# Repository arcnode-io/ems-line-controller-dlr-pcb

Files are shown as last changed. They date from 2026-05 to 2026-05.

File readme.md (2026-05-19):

# DLR PCB 🌡️⚡







> Single-PCB CM4 carrier for a solar-powered, cellular-connected RTU — mounts to a transmission tower cross-arm, integrates SoM + cellular modem + IEEE 738 sensor suite + solar/LiFePO4 power management. Feeds [`dlr-operating-envelope`](https://gitlab.com/arcnode-io/dlr-operating-envelope).

Solar-powered remote terminal unit (RTU) deployed unattended on transmission tower cross-arms. A ~20W solar panel and ~50Wh LiFePO4 battery keep the CM4 running indefinitely with cellular PSM idle. A soldered Quectel BG770A (LTE Cat-M1) publishes sensor data and dynamic ratings to the MQTT broker — no site WiFi or wired backhaul required. The unit is designed for 30-year conductor-adjacent deployment with no scheduled maintenance.

~100x80mm 4-layer industrial carrier. Raspberry Pi CM4 (DF40 dual-connector) + Quectel BG770A LCC + FLIR Lepton 3.5 (SPI) + DHT22 (GPIO) + SI1145 (I2C) + YL-83 (analog via ADS1115). MPPT charger from PV input, LiFePO4 BMS, buck for 5V SoM rail, AP2112K LDO for 3.3V analog front-end. Conformal coated, IP55 when potted in field enclosure.

## System Context

```plantuml
rectangle transmission_tower {
  rectangle field_enclosure {
    rectangle dlr_carrier {
      rectangle cm4_som
      rectangle cellular_module
      rectangle sensors
      rectangle power_mgmt
    }
  }
  rectangle solar_panel
  rectangle lifepo4_battery
  rectangle conductor
}

queue mqtt_broker
rectangle dlr_pst_sim

solar_panel -d- power_mgmt: PV input
power_mgmt -l- lifepo4_battery: charge / discharge
power_mgmt -d- cm4_som: 5V / 3V3
conductor -u- sensors: thermal view\n(FLIR Lepton)
sensors -r- cm4_som: SPI / I2C / GPIO
cm4_som -r- cellular_module: UART + USB2
cellular_module -r- mqtt_broker: LTE Cat-M1
mqtt_broker -r- dlr_pst_sim: tap \n adjustment \n commands
```

The carrier is the physical sensing + edge-compute layer of the DLR feedback loop. Every measurement flows through the IEEE 738 calculation in [`dlr-operating-envelope`](https://gitlab.com/arcnode-io/dlr-operating-envelope) and ultimately determines whether the phase shift transformer adjusts its tap position.

## Board Spec

```mermaid
graph LR
    SOLAR["Solar Panel<br/>~20W 12V"] --> MPPT["MPPT Charger"]
    MPPT --> BAT["LiFePO4 4S<br/>~50Wh + BMS"]
    BAT --> BUCK["Buck<br/>5V 3A"]
    BUCK --> CM4["CM4 SoM<br/>DF40 x2"]
    BUCK --> BG["Quectel BG770A<br/>Cat-M1 LCC"]
    BUCK --> LDO["AP2112K<br/>3.3V LDO"]
    LDO --> ADC["ADS1115<br/>I2C 0x48"]
    LDO --> UV["SI1145<br/>I2C 0x60"]
    CM4 --> FLIR["FLIR Lepton 3.5<br/>SPI0 + GPIO25"]
    CM4 --> DHT["DHT22<br/>GPIO4"]
    CM4 --> ADC
    CM4 --> UV
    ADC --> RAIN["YL-83<br/>Analog 0-3.3V"]

    style SOLAR fill:#dc4,stroke:#333
    style MPPT fill:#a94,stroke:#333
    style BAT fill:#a94,stroke:#333
    style BUCK fill:#a94,stroke:#333
    style LDO fill:#a94,stroke:#333
    style CM4 fill:#4a9,stroke:#333,color:#fff
    style BG fill:#49a,stroke:#333,color:#fff
    style FLIR fill:#49a,stroke:#333,color:#fff
    style DHT fill:#94a,stroke:#333,color:#fff
    style ADC fill:#94a,stroke:#333,color:#fff
    style UV fill:#94a,stroke:#333,color:#fff
    style RAIN fill:#669,stroke:#333,color:#fff
```

## CM4 Pinout

```mermaid
flowchart LR
classDef default fill:transparent,stroke:#333
classDef pwr fill:#4a9,stroke:#333,color:#fff
classDef spi fill:#49a,stroke:#333,color:#fff
classDef i2c fill:#94a,stroke:#333,color:#fff
classDef gpio fill:#a94,stroke:#333,color:#fff
classDef uart fill:#a49,stroke:#333,color:#fff
classDef usb fill:#669,stroke:#333,color:#fff

subgraph cm4 ["CM4 (DF40-100)"]
  p_5v["5V_IN"]
  p_sda["GPIO2 SDA1"]
  p_scl["GPIO3 SCL1"]
  p_g4["GPIO4"]
  p_g25["GPIO25"]
  p_mosi["GPIO10 MOSI"]
  p_miso["GPIO9 MISO"]
  p_sck["GPIO11 SCLK"]
  p_ce0["GPIO8 CE0"]
  p_txd["GPIO14 TXD"]
  p_rxd["GPIO15 RXD"]
  p_usb["USB2 D+/D-"]
end

subgraph onboard ["Carrier Components"]
  flir["FLIR Lepton 3.5"]
  dht["DHT22"]
  si["SI1145"]
  ads["ADS1115"]
  yl["YL-83"]
  bg["BG770A"]
end

p_mosi --> flir
p_miso --> flir
p_sck --> flir
p_ce0 --> flir
p_g25 --> flir
p_g4 --> dht
p_sda --> si
p_scl --> si
p_sda --> ads
p_scl --> ads
ads --> yl
p_txd --> bg
p_rxd --> bg
p_usb --> bg

class p_5v pwr
class p_mosi,p_miso,p_sck,p_ce0 spi
class p_sda,p_scl i2c
class p_g4,p_g25 gpio
class p_txd,p_rxd uart
class p_usb usb
```

## Sensor Interfaces

| Sensor | Interface | CM4 Pins | Sample Rate | Measurement | Feeds IEEE 738 Variable |
|---|---|---|---|---|---|
| FLIR Lepton 3.5 | SPI0 + VSYNC | GPIO 8, 9, 10, 11, 25 | 8.6 Hz (frame) | Conductor surface temp | $R_{thermal}$ |
| DHT22 | GPIO4 (1-Wire) | GPIO 4 | 0.5 Hz | Ambient temp + humidity | $T_{amb}$ |
| SI1145 | I2C (0x60) | GPIO 2, 3 | 10 Hz | UV / Visible / IR irradiance | $\Delta T_{solar}$ |
| YL-83 → ADS1115 | I2C (0x48) ch0 | GPIO 2, 3 | 860 SPS | Rain intensity (0–3.3V analog) | $\Delta T_{rain}$ |

Every sensor reading on this board maps to exactly one term in the IEEE 738 dynamic rating equation:

$$ I_{max} = \sqrt{\frac{q_c + q_r - q_s}{R_{ac}}} $$

## Anemometer Variants

Single PCB + single firmware binary. Variant lives in the **kit BOM** — sensor,
cable harness, PV panel, and battery differ per SKU. Both sensors speak
NMEA 0183 (`$..MWV`) over RS-485, so the firmware driver is talker-agnostic.

### Kit BOM

| Component | High-wind kit (`DLR-CRN-HW`) | Low-wind kit (`DLR-CRN-LW`) |
|---|---|---|
| PCB | `dlr-pcb-v1` (same) | `dlr-pcb-v1` (same) |
| Firmware | `dlr-operating-envelope` (same binary) | `dlr-operating-envelope` (same binary) |
| Sensor | Calypso ULP STD | Vaisala WMT702 |
| Sensor wire protocol | NMEA `$IIMWV` over RS-485 | NMEA `$WIMWV` over RS-485 |
| Sensor accuracy (V<2 m/s) | ±5 % + 0.2 m/s offset (1 m/s threshold) | **±0.1 m/s** (0.01 m/s threshold) |
| Sensor op temp | unspecified (consumer-grade) | -10 to +60 °C |
| Cable harness | 5 m bare-wire to M12-5P | 5 m Cannon Trident 19-way to M12-5P |
| PV panel | 20 W | **30 W** |
| Battery | 50 Wh LiFePO4 | **100 Wh LiFePO4** |
| Sticker | `HW-1.0` | `LW-1.0` |
| Kit cost (approx) | ~$650 | ~$2350 |

### When to deploy which variant

Per-site SKU pick uses NREL WIND Toolkit climatology (or customer SCADA wx
history when available). Threshold: fraction-of-year with V_w < 1 m/s
perpendicular to conductor.

| Climatology | Variant | Why |
|---|---|---|
| ≤ 15 % yr V_w < 1 m/s (ridge / coastal / open plain w/ mean ≥ 6 m/s) | high-wind | uplift slice below 1 m/s is marginal; static fallback below threshold is fine |
| > 15 % yr V_w < 1 m/s (valley / sheltered / open plain w/ mean ≤ 5 m/s) | low-wind | uplift slice is material; pay $1.7 k premium to capture it |

### Fallback policy (both variants)

When the sensor reports `void` status, times out, or has a checksum/parse
error, the driver returns `None`. The IEEE 738 layer collapses None →
`V_w = 0.0` → natural-convection-only ampacity = the conductor's static
rating. Same conservative fallback used for the icing-fallback policy.

### Variant power budget

| | High-wind | Low-wind |
|---|---|---|
| Sensor continuous draw | 1 mW | 480 mW |
| System daily energy | 29.1 Wh | 40.6 Wh |
| Winter PV harvest (worst) | 45 Wh | 67.5 Wh |
| Winter margin | 1.55× | **1.66×** |
| Battery autonomy at 0 PV | 1.58 d | **2.22 d** |

Low-wind variant's 30 W / 100 Wh upgrade absorbs the WMT702's higher draw and
restores both winter margin and 2-day autonomy.

## Power Budget

| Rail | Source | Consumer | Idle (PSM) | Typical | Peak |
|---|---|---|---|---|---|
| 5V | Buck | CM4 | 80 mA | 1400 mA | 3000 mA (boot) |
| 5V | Buck | Quectel BG770A | <1 mA | 100 mA | 250 mA (TX) |
| 5V | Buck | FLIR Lepton 3.5 | 150 mA | 150 mA | 650 mA (shutter) |
| 5V | Buck | DHT22 | 1.5 mA | 1.5 mA | 2.5 mA |
| 3.3V | AP2112K LDO | ADS1115 + SI1145 + YL-83 | 9 mA | 9 mA | 14 mA |
| | | **Total @ 5V equiv** | **240 mA** | **1660 mA** | **3920 mA** |

Daily energy with realistic CM4-always-on idle + 1/min sensor wake + 1/15 min cellular TX: **~29 Wh/day** (derived in `theory.ipynb`). A 50 Wh battery (90% DoD) gives ~1.6 days autonomy with no PV. A 20W panel at 2.5 sun-hours/day (winter Northeast US worst case) delivers ~45 Wh/day after MPPT η — **1.55x winter margin**, 2.5x annual avg.

## Environmental

| Parameter | Spec | Notes |
|---|---|---|
| Operating temp | -20°C to +85°C | CM4 commercial spec; cold-start heater required below -20°C |
| Conformal coat | Dow Corning 1-2577 | Applied post-assembly, mask connectors |
| Enclosure rating | IP55 (with field enclosure) | Board alone is not rated |
| Vibration | IEC 60068-2-6 (5–500 Hz, 2g) | Transmission tower wind loading |
| Expected service life | 30 years | Matches conductor replacement cycle |
| MTBF | >200,000 hours | Derated per MIL-HDBK-217F |
| Mounting | M3 standoffs, 4-corner | Single rigid PCB — no stack |

## Fabrication Pipeline

The project fabricates **two PCBs** (per ADR-013): the main carrier and the Lepton daughterboard. Both go through the same flow.

```
 1. uv run poe notebook         → theory.ipynb: power budget + signal integrity
 2. uv run poe build            → SKiDL netlist (main carrier + daughterboard)
 3. uv run poe sim              → validate buck regulation, MPPT, I2C/SPI timing
 4. /generate-schematic         → professional .kicad_sch (each PCB)

    ┌──────────────────────────────────────────────────────┐
    │  HUMAN: open pcbnew, import netlist, save, close     │
    └──────────────────────────────────────────────────────┘

 5. /layout-pcb                 → place + autoroute + ground pour + DRC

    ┌──────────────────────────────────────────────────────┐
    │  HUMAN: review SVG, adjust pcb_placement.yaml        │
    └──────────────────────────────────────────────────────┘

 6. uv run poe validate-asm     → DRC 0 errors
 7. uv run poe generate-asm     → gerbers + BOM + CPL (per board)
```

## Layer Stack

| Layer | Use |
|---|-----|
| F.Cu | Signal — high-speed (SPI 20MHz, USB2.0 to BG770A) |
| In1.Cu | GND pour (unbroken under FLIR + cellular module) |
| In2.Cu | Power planes — 5V, 3V3, BAT |
| B.Cu | Signal — low-speed (I2C, GPIO, UART) |

Unbroken ground plane under the Lepton is critical — SPI runs at 20 MHz and the thermal imager is noise-sensitive. USB2.0 to the BG770A is differential-routed at 90Ω matched impedance with GND directly below. Analog traces from YL-83 to ADS1115 are guard-ringed on F.Cu. Cellular antenna is 50Ω microstrip to a u.FL connector.

## Project Structure

```
├── pyproject.toml              # Dependencies and build config
├── theory.ipynb                # Power budget + signal integrity derivation
├── sim/
│   ├── model.py                # Buck regulation, LDO dropout, I2C/SPI timing
│   └── test_run.py             # Assert simulation matches theory
├── cad/
│   ├── netlist/
│   │   ├── model.py            # Top-level SKiDL circuit (main carrier)
│   │   ├── power.py            # MPPT + BMS + buck + LDO
│   │   ├── som.py              # CM4 DF40 connector + decoupling
│   │   ├── cellular.py         # BG770A + SIM holder + u.FL
│   │   ├── sensors.py          # FLIR (FFC), DHT22, SI1145, ADS1115, YL-83
│   │   ├── connectors.py       # Battery + debug + USB-C commissioning
│   │   └── lepton_daughter.py  # Daughterboard SKiDL (Molex socket + FFC)
│   ├── lepton_daughter/        # Second PCB (per ADR-013) — Lepton + bracket
│   ├── schematic/              # /generate-schematic output
│   ├── assembly/               # CadQuery → GLB pipeline (build_assembly.py)
│   ├── layout_spec.yaml        # Schematic block layout
│   ├── pcb_placement.yaml      # Main-PCB component positions
│   └── drawing-sheet.kicad_wks # Title block
├── output/
│   ├── drawings/               # Schematic SVG + PDF
│   ├── gerbers/                # Fabrication files
│   └── fab/                    # BOM + CPL for assembly
└── readme.md                   # This file
```

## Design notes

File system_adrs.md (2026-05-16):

# DLR Carrier Board — Architecture Decision Records

Captures architectural and component decisions for the DLR PCB. New decisions append as ADR-NNN; supersedes are explicit. Date format ISO 8601.

## Index

| # | Decision | Class |
|---|---|---|
| 001 | Single-PCB CM4 carrier | Architecture |
| 002 | Battery — LiFePO4 4S | Architecture |
| 003 | Cellular bands — NA-only | Architecture |
| 004 | Solar panel — 20W | Architecture |
| 005 | I2C clock — 400 kHz | Architecture |
| 006 | Antenna form — u.FL + external blade | Architecture |
| 007 | 5V buck — TI LMR33630 | Component |
| 008 | MPPT charger — TI BQ24650 | Component |
| 009 | BMS — JBD-SP04S013 (on-pack) | Component |
| 010 | BG770A 3.8V LDO — TI LP5907 | Component |
| 011 | Level shifter — TI TXS0108E | Component |
| 012 | u.FL connector — Hirose U.FL-R-SMT-1(10) | Component |
| 013 | Lepton daughterboard for aim flexibility | Architecture |

---

## ADR-001: Single-PCB CM4 Carrier (vs Pi HAT)

**Status:** Accepted **Date:** 2026-05-08

### Context
30-yr maintenance-free transmission tower deployment, IP55 potted enclosure, IEC 60068-2-6 vibration (5–500 Hz, 2g), −20 to +85°C operating temp, solar+LiFePO4 budget. Initial readme proposed a Pi 5 HAT stack.

### Decision
Single-PCB ~100×80mm 4-layer carrier with Raspberry Pi CM4 mounted via DF40 connector pair. All cellular, sensor, and power-management circuitry on the same board.

### Rationale
- Pi 5 is consumer-grade (0–50°C) and won't survive spec'd environment
- 40-pin HAT stack is a vibration failure mode (connector fretting + lever arm)
- Stock Pi has unused HDMI/audio/USB hub circuitry burning solar budget for 30 yrs
- USB-A cellular dongles are the worst industrial connector
- Conformal-coating a Pi is messy (HDMI/USB ports = giant openings)

### Alternatives Considered
| Option | Tradeoff |
|---|---|
| Pi HAT stack | Faster iteration, fails environment spec |
| iMX6ULL or STM32MP1 SoM | More industrial pedigree, worse software ecosystem, longer integration |
| STM32H7 + PSRAM (no Linux) | Lowest power, ~6 mo firmware vs ~3 wk Python |

### Consequences
- 4-layer 1.6mm board with controlled impedance (50Ω microstrip + 90Ω diff)
- Operating temp pinned at −20 to +85°C (CM4 commercial spec)
- Cold-start heater needed below −20°C
- All schematic + layout effort owned by us

---

## ADR-002: Battery — LiFePO4 4S

**Status:** Accepted **Date:** 2026-05-08

### Context
Outdoor solar-powered RTU with 30-yr cycle life. Battery range must be compatible with downstream buck Vin.

### Decision
4S LiFePO4 pack: V_min = 10.0V, V_nom = 12.8V, V_max = 14.6V. 4 Ah cell → ~50 Wh nominal.

### Rationale
4S sits in the Vin range of common 12V-class bucks with transient margin. LiFePO4 has 90% DoD tolerance, 3000+ cycle life, and cold-temp safety (no thermal runaway risk in a sealed enclosure).

### Alternatives Considered
| Option | Tradeoff |
|---|---|
| LiFePO4 3S (9.6V nom) | Cheaper, but 7.5V cutoff below most buck Vin specs |
| Li-ion 3S | Higher energy density, worse thermal safety |
| Lead-acid | Cheap, heavy, low cycle life, poor cold-temp |

### Consequences
- Buck must accept 10.0–14.6V continuously (1.46x ratio)
- BMS must handle 4-cell balancing + 0°C low-temp charge cutoff
- 50 Wh autonomy = 1.58 days at zero PV → flagged for upgrade to 100 Wh

---

## ADR-003: Cellular Bands — NA-Only

**Status:** Accepted **Date:** 2026-05-08

### Context
Cat-M1 RTU deployment scoped to North American utility customers initially. Module SKU + antenna selection depend on band targets.

### Decision
NA-only Cat-M1 bands: B12/B13/B71/B85 (600–960 MHz LB).

### Rationale
NA-only narrows BG770A SKU choice (BG770A-NA), reduces antenna BOM (single LB element vs multiband), avoids global certification cost (FCC/IC only).

### Alternatives Considered
| Option | Tradeoff |
|---|---|
| Global multiband | Larger antenna, dual-band cert, higher cost, premature for utility scope |
| EU + NA | Splits cert effort, no current customer pull |

### Consequences
- BG770A-NA SKU only
- Antenna spec: 600–960 MHz, ~3 dBi, single-band blade
- Future global expansion = new SKU + new antenna (acceptable)

---

## ADR-004: Solar Panel — 20W

**Status:** Accepted **Date:** 2026-05-08

### Context
Daily energy budget at 1/min sampling + 1/15-min cellular TX = 29.1 Wh/day (theory.ipynb). Need PV sizing for ≥1.5x winter margin.

### Decision
20W mono panel, ~17V Vmp, ~21V Voc.

### Rationale
20W × 2.5 sun-hours × 0.90 MPPT η = 45 Wh/day winter worst case = 1.55x margin over 29 Wh/day budget. Annual avg = 2.5x. Panel envelope (~30×40 cm, ~2 kg) is mechanically reasonable for a tower cross-arm.

### Alternatives Considered
| Option | Tradeoff |
|---|---|
| 10W panel | Insufficient — winter margin <1x |
| 30–40W panel | Larger envelope, unnecessary for IEEE 738 sample rate |

### Consequences
- MPPT charger Vin range must cover 17V Vmp comfortably (5–28V is fine)
- Panel mounting hardware sized for ~2 kg + wind/ice loading
- If sample rate ever bumps to 1Hz, panel must scale to ~125W (separate ADR)

---

## ADR-005: I2C Clock — 400 kHz

**Status:** Accepted **Date:** 2026-05-08

### Context
On-board I2C bus carries ADS1115 (0x48) + SI1145 (0x60) + 2 spare slots. Pull-up sizing depends on clock rate.

### Decision
400 kHz fast mode (UM10204 Rev 7.0).

### Rationale
ADS1115 supports up to 3.4 MHz, SI1145 up to 400 kHz. Fast mode is the highest rate the slowest device supports. With 75 pF estimated C_bus and 2.2 kΩ pull-ups, rise time = 140 ns vs 300 ns spec (53% margin).

### Alternatives Considered
| Option | Tradeoff |
|---|---|
| 100 kHz standard mode | Larger pull-ups OK, but slower readings limit sensor poll rate headroom |
| 1 MHz fast-mode-plus | SI1145 exceeded; would force discrete buffer per device |

### Consequences
- 2.2 kΩ pull-ups on SDA/SCL (E24, in 967Ω–4.72kΩ range)
- C_bus budget: 75 pF (verify after layout)

---

## ADR-006: Antenna Form — u.FL + External Blade

**Status:** Accepted **Date:** 2026-05-08

### Context
Tower-top deployment needs reliable RF link to a Cat-M1 base station. Antenna choice trades cost vs gain vs durability.

### Decision
On-board u.FL connector → external pigtail (RG316) → N-female bulkhead → external blade antenna.

### Rationale
u.FL is the canonical cellular module connector; pigtail to N-female bulkhead gives mechanical robustness at the enclosure wall. External blade provides ~3 dBi at 600–960 MHz vs negative gain for an internal PCB trace antenna.

### Alternatives Considered
| Option | Tradeoff |
|---|---|
| On-board PCB trace antenna (Taoglas FXUB63) | No external connector, but gain too low for tower-top |
| MMCX/SMA on-board (no pigtail) | More robust mechanically, 10× footprint, overkill inside potted enclosure |
| Whip with magnetic base | Won't work on transmission tower (lattice, not steel) |

### Consequences
- 50Ω microstrip from BG770A ANT to u.FL (≤30 mm preferred per theory section 5)
- External antenna + pigtail are accessories, specified at integration time
- Pi-network footprint provisioned on-board for VSWR tuning during EVT

---

## ADR-007: 5V Buck — TI LMR33630ADDAR

**Status:** Accepted **Date:** 2026-05-08

### Context
Battery 10–14.6V → 5V/3A continuous + 3.92A boot inrush. Sits upstream of CM4 + BG770A LDO + sensors.

### Decision
TI LMR33630ADDAR, HSOIC-8, programmable Fsw=400 kHz, paired with 470 µF aluminum polymer bulk cap on 5V to absorb CM4 boot inrush.

### Rationale
3.8–36V Vin = huge headroom over 14.6V max. 3A integrated synchronous FETs, ~92% peak η, industrial −40 to +125°C, hand-solderable, ~$1.50.

### Alternatives Considered
| Option | Tradeoff |
|---|---|
| TI TPS62133 | Smaller QFN, but Vin tops at 15V — only 0.4V margin over V_BAT_MAX |
| TI TPS54331 | Asynchronous → ~80% light-load η, hurts PSM idle budget |
| LM2596 (legacy) | Cheap + ubiquitous, ~75% η wastes 25% of solar budget |
| MPS MP2459 | Undersized at <1A |

### Consequences
- Bulk cap on 5V rail is mandatory (boot inrush mitigation)
- Programmable Fsw lets us trade efficiency vs component size at layout time
- 92% efficiency vs 90% theory assumption gives small headroom in derivation

---

## ADR-008: MPPT Charger — TI BQ24650RVAR

**Status:** Accepted **Date:** 2026-05-08

### Context
20W panel input → 4S LiFePO4 charge. Needs true MPPT (not just input-voltage regulation) and adjustable charge profile.

### Decision
TI BQ24650RVAR, VQFN-16. R_SR = 20 mΩ for 2A charge (0.5C of 4 Ah cell). VINREG set to 16.8V (~80% of Voc). VFB divider gives 14.6V V_charge.

### Rationale
True MPPT buck charger via VINREG pin (not just CV input regulation). 5–28V Vin covers 17V Vmp + transients. Programmable charge V/I via resistor dividers. Industrial −40 to +85.

### Alternatives Considered
| Option | Tradeoff |
|---|---|
| LTC4015 | LiFePO4-aware + I²C telemetry, but 2× cost + 38-pin QFN, overkill |
| MP2731 | Cheap, designed for 1S phone use case — won't drive 4S/14.6V |
| CN3791 | Asian-market chip, sparse docs, max 8.4V output (2S only) |
| Discrete LT3652 + LTC4054 | Most flexible, but 2 ICs + more passives, harder to debug |

### Consequences
- Cell balancing + low-temp cutoff are NOT in BQ24650 → handled by separate BMS (ADR-009)
- TS pin can monitor pack NTC; partially overlaps with BMS — leave NC unless needed
- R_SR = 20 mΩ ±1% sense resistor required

---

## ADR-009: BMS — JBD-SP04S013 (On-Pack)

**Status:** Accepted **Date:** 2026-05-08

### Context
LiFePO4 4S pack needs cell balancing + per-cell over/undervoltage cutoff + low-temp charge inhibit (charging below 0°C destroys LiFePO4 cells permanently).

### Decision
JBD-SP04S013 (or equivalent commoditized 4S LiFePO4 BMS PCB), mounted **physically on the battery pack**, NOT on the carrier PCB. 15A continuous discharge, balancing, 0°C low-temp cutoff, ~150 µA quiescent, ~$8.

### Rationale
Designing a discrete BMS on the carrier multiplies layout complexity, MOSFET sourcing risk, and validation effort for a problem that's already commoditized. On-pack mounting means the carrier sees only `BAT+`/`BAT-` — drastically simpler PCB.

### Alternatives Considered
| Option | Tradeoff |
|---|---|
| Discrete on-carrier (TI BQ77216 + dual N-FETs) | ~6 ICs + 8 FETs + 30 passives added; ~3 wks of layout + validation |
| Discrete on-carrier (Analog Devices LTC6804) | Best-in-class, $15 IC, designed for EV/grid storage — massive overkill |
| No BMS | NEVER acceptable — cell imbalance kills LiFePO4 in <100 cycles |
| Bioenno BLF-1204AS (battery + BMS combined) | Zero design effort but 3× cost, locks vendor |

### Consequences
- Carrier PCB has 2-pin battery input only (no cell sense lines, no protection FETs)
- Battery is a swappable assembly serviced separately — better 30-yr maintenance story
- BMS quiescent (150 µA × 12.8V × 24h = 0.046 Wh/day) is negligible vs 29 Wh/day budget

---

## ADR-010: BG770A 3.8V LDO — TI LP5907MFX-3.8

**Status:** Accepted **Date:** 2026-05-08

### Context
BG770A VBAT spec is 3.4–4.3V (Li-ion class). Cannot power directly from 4S battery (10–14.6V) or 5V buck. Cellular RF is sensitive to LDO ripple.

### Decision
TI LP5907MFX-3.8, SOT-23-5. Fixed 3.8V output (no resistor divider), 250 mA, 6.5 µVrms ultra-low-noise, 16 µA quiescent.

### Rationale
LP5907 is the LDO Quectel's BG770A hardware design guide explicitly recommends. Fixed 3.8V SKU exactly matches Quectel's typical, no divider drift. Ultra-low noise prevents desensing the cellular receiver.

### Alternatives Considered
| Option | Tradeoff |
|---|---|
| MPS MP2161 (3.8V buck from 5V) | Higher η, but switching noise into RF chain — needs filtering, not worth it for ~0.18 Wh/day savings |
| TPS73801 (adjustable LDO) | 1A capacity, but higher quiescent + divider drift |
| AP2112-3.3 (re-use 3V3 LDO) | Below BG770A's 3.4V minimum — TX brownouts |
| Adjustable LDO from battery direct | 12V × 250mA peak = 3.6W heat, thermally infeasible |

### Consequences
- Daily energy budget already accounts for BG770A draw at 5V-equivalent (LDO η ~80%)
- LP5907 EN pin wired to a CM4 GPIO → power-cycle option for stuck cellular state
- 250 mA capacity covers TX peaks with margin

---

## ADR-011: Level Shifter — TI TXS0108E

**Status:** Accepted **Date:** 2026-05-08

### Context
CM4 GPIO is 3.3V CMOS, BG770A I/O is 1.8V CMOS. 8 lines need shifting: TXD, RXD, PWRKEY, RESET, DTR, STATUS, NETLIGHT, RING. (USB doesn't need shifting — USB 2.0 spec on both sides.)

### Decision
TI TXS0108E, TSSOP-20. 8-channel auto-direction-sensing, OD-compatible, 1.65–5.5V on either side, ~1.2 Mbps OD / 50 Mbps push-pull.

### Rationale
Mixed signal types on BG770A side (some OD outputs) — TXS0108E handles both. Single-IC vs 16 discrete transistors. Auto-direction means no DIR pin to manage. Quectel reference designs use this part.

### Alternatives Considered
| Option | Tradeoff |
|---|---|
| TI TXB0108 | Stronger push-pull drive, but fails on OD signals — risky if STATUS/NETLIGHT are OD |
| Discrete BSS138 + 10kΩ pulls | Cheapest, but 16 transistors + 16 resistors = 50× layout area |
| 4× SN74LVC1T45 single-channel | Per-channel direction control, but 4 ICs + 4 GPIOs consumed |
| Series resistor only | Will damage BG770A inputs over time via protection diodes |

### Consequences
- VccA = 1.8V (sourced from BG770A VDD_EXT, ~50 mA available)
- VccB = 3.3V (from existing AP2112K)
- OE pin → CM4 GPIO with pull-down for boot-time isolation
- 100 nF decoupling on each Vcc

---

## ADR-012: u.FL Connector — Hirose U.FL-R-SMT-1(10) + Pi-Match

**Status:** Accepted **Date:** 2026-05-08

### Context
On-board RF chain from BG770A ANT pin to external pigtail. Form-factor decision (ADR-006) selected u.FL; this ADR pins the specific connector and matching topology.

### Decision
Hirose U.FL-R-SMT-1(10) connector + 3-pad Pi-network footprint between BG770A ANT and u.FL. Default: 0Ω series jumper, NC/NC shunts. Components populated only if EVT VSWR testing requires.

### Rationale
Hirose is the canonical industry u.FL — every cellular module reference design uses it. Pi-network footprint is free in layout space and preserves tuning option without a respin.

### Alternatives Considered
| Option | Tradeoff |
|---|---|
| Molex 73412-0110 | Functionally equivalent, sometimes better-stocked, but pigtails specced for Hirose may not seat as well |
| Skip Pi-network, direct trace | One less footprint, but no recourse if VSWR is bad at EVT |
| MMCX/SMA on-board | More robust mechanically, but 10× area + 4–5× cost, overkill inside potted enclosure |

### Consequences
- 50Ω microstrip from BG770A ANT → Pi-network → u.FL center pin
- u.FL placed near board edge for pigtail clearance + 10×10mm keepout for cable bend radius
- Off-board accessories (pigtail + N-female bulkhead + blade antenna) specified at integration, not PCB design

---

## ADR-013: Lepton Daughterboard for Aim Flexibility

**Status:** Accepted **Date:** 2026-05-10

### Context
ADR-001 mandated a single-PCB carrier with all sensor, cellular, and power-management circuitry on one board, motivated by stacked-Pi-HAT vibration failures over 30-yr deployments. Cross-arm DLR deployment requires the FLIR Lepton 3.5 lens to aim at a conductor ~1.5 m below the cross-arm; with a sky-facing solar panel constraint and the lens perpendicular to the main PCB, no monolithic-board orientation satisfies both.

### Decision
Split the Lepton onto a small (~25 × 40 mm) daughterboard linked to the main PCB by a 14-pin 0.5 mm-pitch FFC. Daughterboard mounts to a sheet-metal bracket with M3 pivot + M3 arc-slot lock, allowing ±15° aim adjustment at integration time. Sealed industrial USB-C commissioning port on the main carrier provides live thermal preview to a laptop while the integrator sets aim.

### Rationale
ADR-001's spirit was to avoid stacked compute (Pi 5 HAT). A passive sensor daughterboard with no active electronics beyond the Lepton socket and decoupling is not the failure class ADR-001 was guarding against. The daughterboard inherits the 30-yr robustness of the main carrier (same conformal coat, same enclosure, same potting) and adds no compute.

### Alternatives Considered
| Option | Tradeoff |
|---|---|
| Lens out the side via vertical PCB | CM4 + cellular re-layout, vibration cantilever, antenna re-route. Overkill for an optical aim problem. |
| 45° gold folding mirror inside enclosure | Field-degradation: dust, condensation, ice, biofilm. Mirror-axis drift over 30 yrs. |
| Right-angle Lepton breakout (commercial) | Locks us to a specific vendor SKU with EOL risk; still needs a daughterboard or adapter. |
| GroupGets Lepton breakout as the daughterboard | Pre-designed, but vendor EOL risk over 30 yrs and no native FFC connection — adapter board still needed. |

### Consequences
- Two PCBs in the project: `cad/dlr_carrier.*` (main) and `cad/lepton_daughter/*` (new). Two KiCad projects, two BOM/CPL files, two Gerber sets to fab; ~+$15 marginal fab cost per unit at low volume.
- J8 footprint on main PCB changes from a 14-pin 2.54 mm THT header to a Hirose FH12-14S-0.5SH FFC connector. Pin map preserves the GroupGets 14-pin Lepton breakout signal order so the schematic on the daughterboard is reusable.
- Aim is set once at integration with lockwasher + Loctite 243; no field-accessible knob (an external knob would be an IP55 / O-ring / corrosion-over-30-yrs liability).
- Sealed industrial USB-C commissioning port (J12) is mandatory — without it the integrator can't see the live thermal frame to set aim.
- ADR-001 retains force for compute and the bulk of sensor / power circuitry; ADR-013 is a scoped exception covering only the Lepton optical chain.

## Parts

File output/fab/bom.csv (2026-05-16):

Designator | Comment | Footprint | Quantity
C1,C3 | 22uF | Capacitor_SMD:C_1206_3216Metric | 2
C2,C5,C6,C9,C14-C17,C19,C20,C23-C28 | 100nF | Capacitor_SMD:C_0402_1005Metric | 16
C4 | 4.7uF | Capacitor_SMD:C_0805_2012Metric | 1
C7 | 470uF | Capacitor_SMD:CP_Elec_8x10 | 1
C8 | 22uF | Capacitor_SMD:C_0805_2012Metric | 1
C10-C13 | 1uF | Capacitor_SMD:C_0402_1005Metric | 4
C18 | 4.7uF | Capacitor_SMD:C_0402_1005Metric | 1
C21,C22 | DNP | Capacitor_SMD:C_0402_1005Metric | 2
C29 | 10nF | Capacitor_SMD:C_0402_1005Metric | 1
D1 | SS34 | Diode_SMD:D_SMA | 1
J1 | PV_IN | TerminalBlock_Phoenix:TerminalBlock_Phoenix_MKDS-1,5-2-5.08_1x02_P5.08mm_Horizontal | 1
J2 | BQ24650 | Package_DFN_QFN:HVQFN-16-1EP_3x3mm_P0.5mm_EP1.5x1.5mm | 1
J3 | BAT | TerminalBlock_Phoenix:TerminalBlock_Phoenix_MKDS-1,5-2-5.08_1x02_P5.08mm_Horizontal | 1
J4 | LMR33630ADDA | Package_SO:HSOP-8-1EP_3.9x4.9mm_P1.27mm_EP2.41x3.1mm | 1
J5 | CM4_J2 | Connector_Hirose_DF40:Hirose_DF40HC(3.0)-40DS-0.4V_2x20_P0.4mm | 1
J6 | U.FL | Connector_Coaxial:U.FL_Hirose_U.FL-R-SMT-1_Vertical | 1
J7 | SIM | Connector_Card:microSIM_JAE_SF53S006VCBR2000 | 1
J8 | FLIR_LEPTON | Connector_PinHeader_2.54mm:PinHeader_1x14_P2.54mm_Vertical | 1
J9 | SI1145 | Connector_PinHeader_2.54mm:PinHeader_1x05_P2.54mm_Vertical | 1
J10 | YL-83 | Connector_PinHeader_2.54mm:PinHeader_1x04_P2.54mm_Vertical | 1
J11 | DEBUG_UART | Connector_PinHeader_2.54mm:PinHeader_1x04_P2.54mm_Vertical | 1
L1 | 6.8uH | Inductor_SMD:L_Bourns-SRN6028 | 1
L2 | 10uH | Inductor_SMD:L_Bourns-SRN8040_8x8.15mm | 1
R1 | 20m | Resistor_SMD:R_1206_3216Metric | 1
R2 | 39.2k | Resistor_SMD:R_0402_1005Metric | 1
R3,R7-R9 | 10k | Resistor_SMD:R_0402_1005Metric | 4
R4 | 47k | Resistor_SMD:R_0402_1005Metric | 1
R5 | 0R | Resistor_SMD:R_0402_1005Metric | 1
R6 | 100k | Resistor_SMD:R_0402_1005Metric | 1
R10,R11 | 2.2k | Resistor_SMD:R_0402_1005Metric | 2
U1 | AP2112K-3.3 | Package_TO_SOT_SMD:SOT-23-5 | 1
U2 | LP5907MFX-3.8 | Package_TO_SOT_SMD:SOT-23-5 | 1
U3 | BG770A-NA | RF_GSM:Quectel_BG95 | 1
U4 | TXS0108E | Package_SO:TSSOP-20_4.4x6.5mm_P0.65mm | 1
U5 | DHT22 | Sensor:Aosong_DHT11_5.5x12.0_P2.54mm | 1
U6 | ADS1115 | Package_SO:MSOP-10_3x3mm_P0.5mm | 1

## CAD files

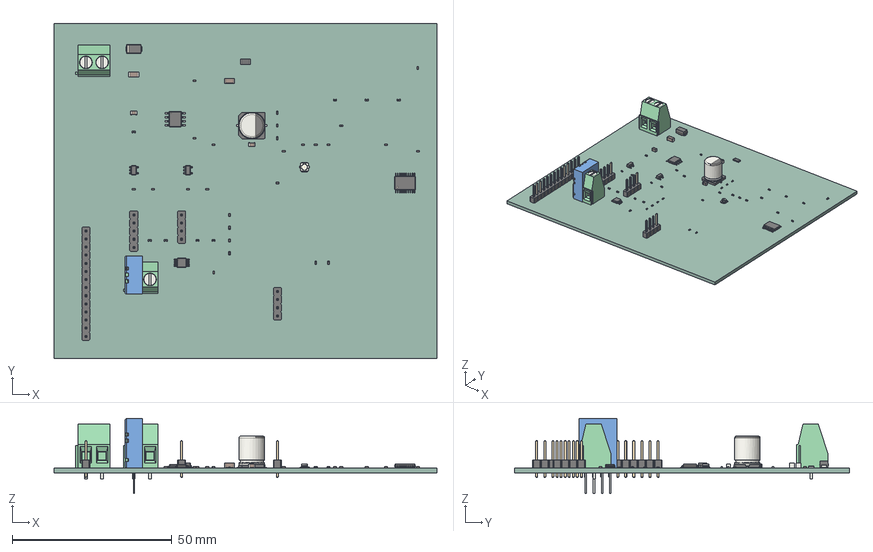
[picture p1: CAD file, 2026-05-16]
output/dlr_carrier_pcb.step
120.0 x 105.0 x 23.5 mm
R_0402_1005Metric x 10
TSSOP-20_4.4x6.5mm_P0.65mm
MSOP-10_3x3mm_P0.5mm
C_0402_1005Metric x 24
PinHeader_1x04_P2.54mm_Vertical x 2
CP_Elec_8x10
C_1206_3216Metric x 2
C_0805_2012Metric x 2
PinHeader_1x05_P2.54mm_Vertical
SOT-23-5 x 2
U.FL_Hirose_U.FL-R-SMT-1_Vertical
TerminalBlock_Phoenix_MKDS-1,5-2-5.08_1x02_P5.08mm_Horizontal x 2
HSOP-8-1EP_3.9x4.9mm_P1.27mm_EP2.41x3.1mm
Aosong_DHT11_5.5x12.0_P2.54mm
D_SMA
R_1206_3216Metric
PinHeader_1x14_P2.54mm_Vertical
dlr_carrier_PCB

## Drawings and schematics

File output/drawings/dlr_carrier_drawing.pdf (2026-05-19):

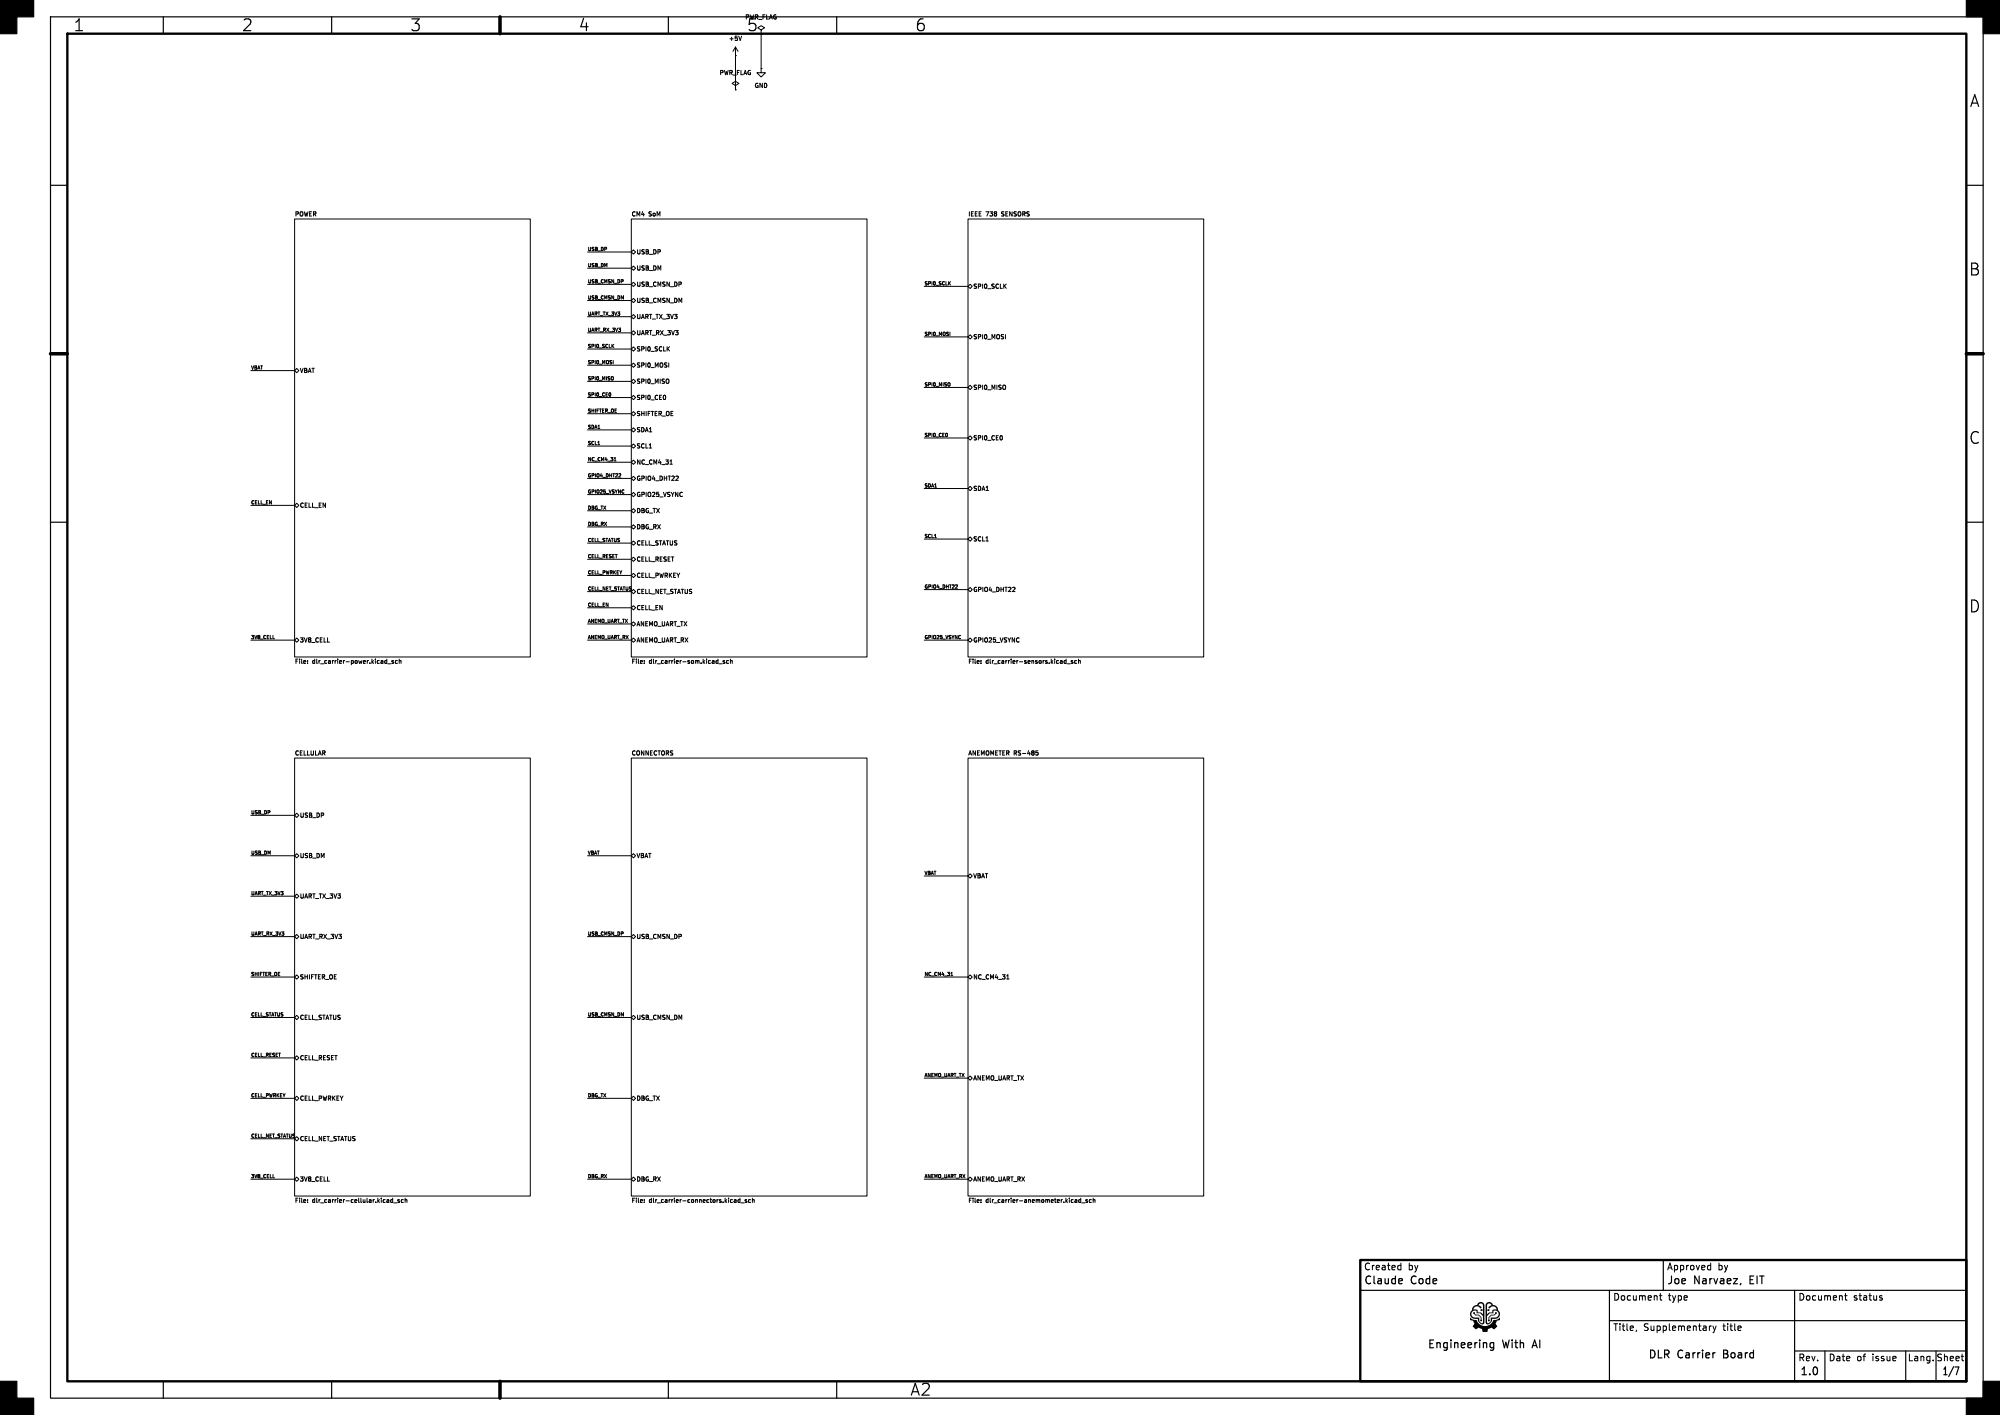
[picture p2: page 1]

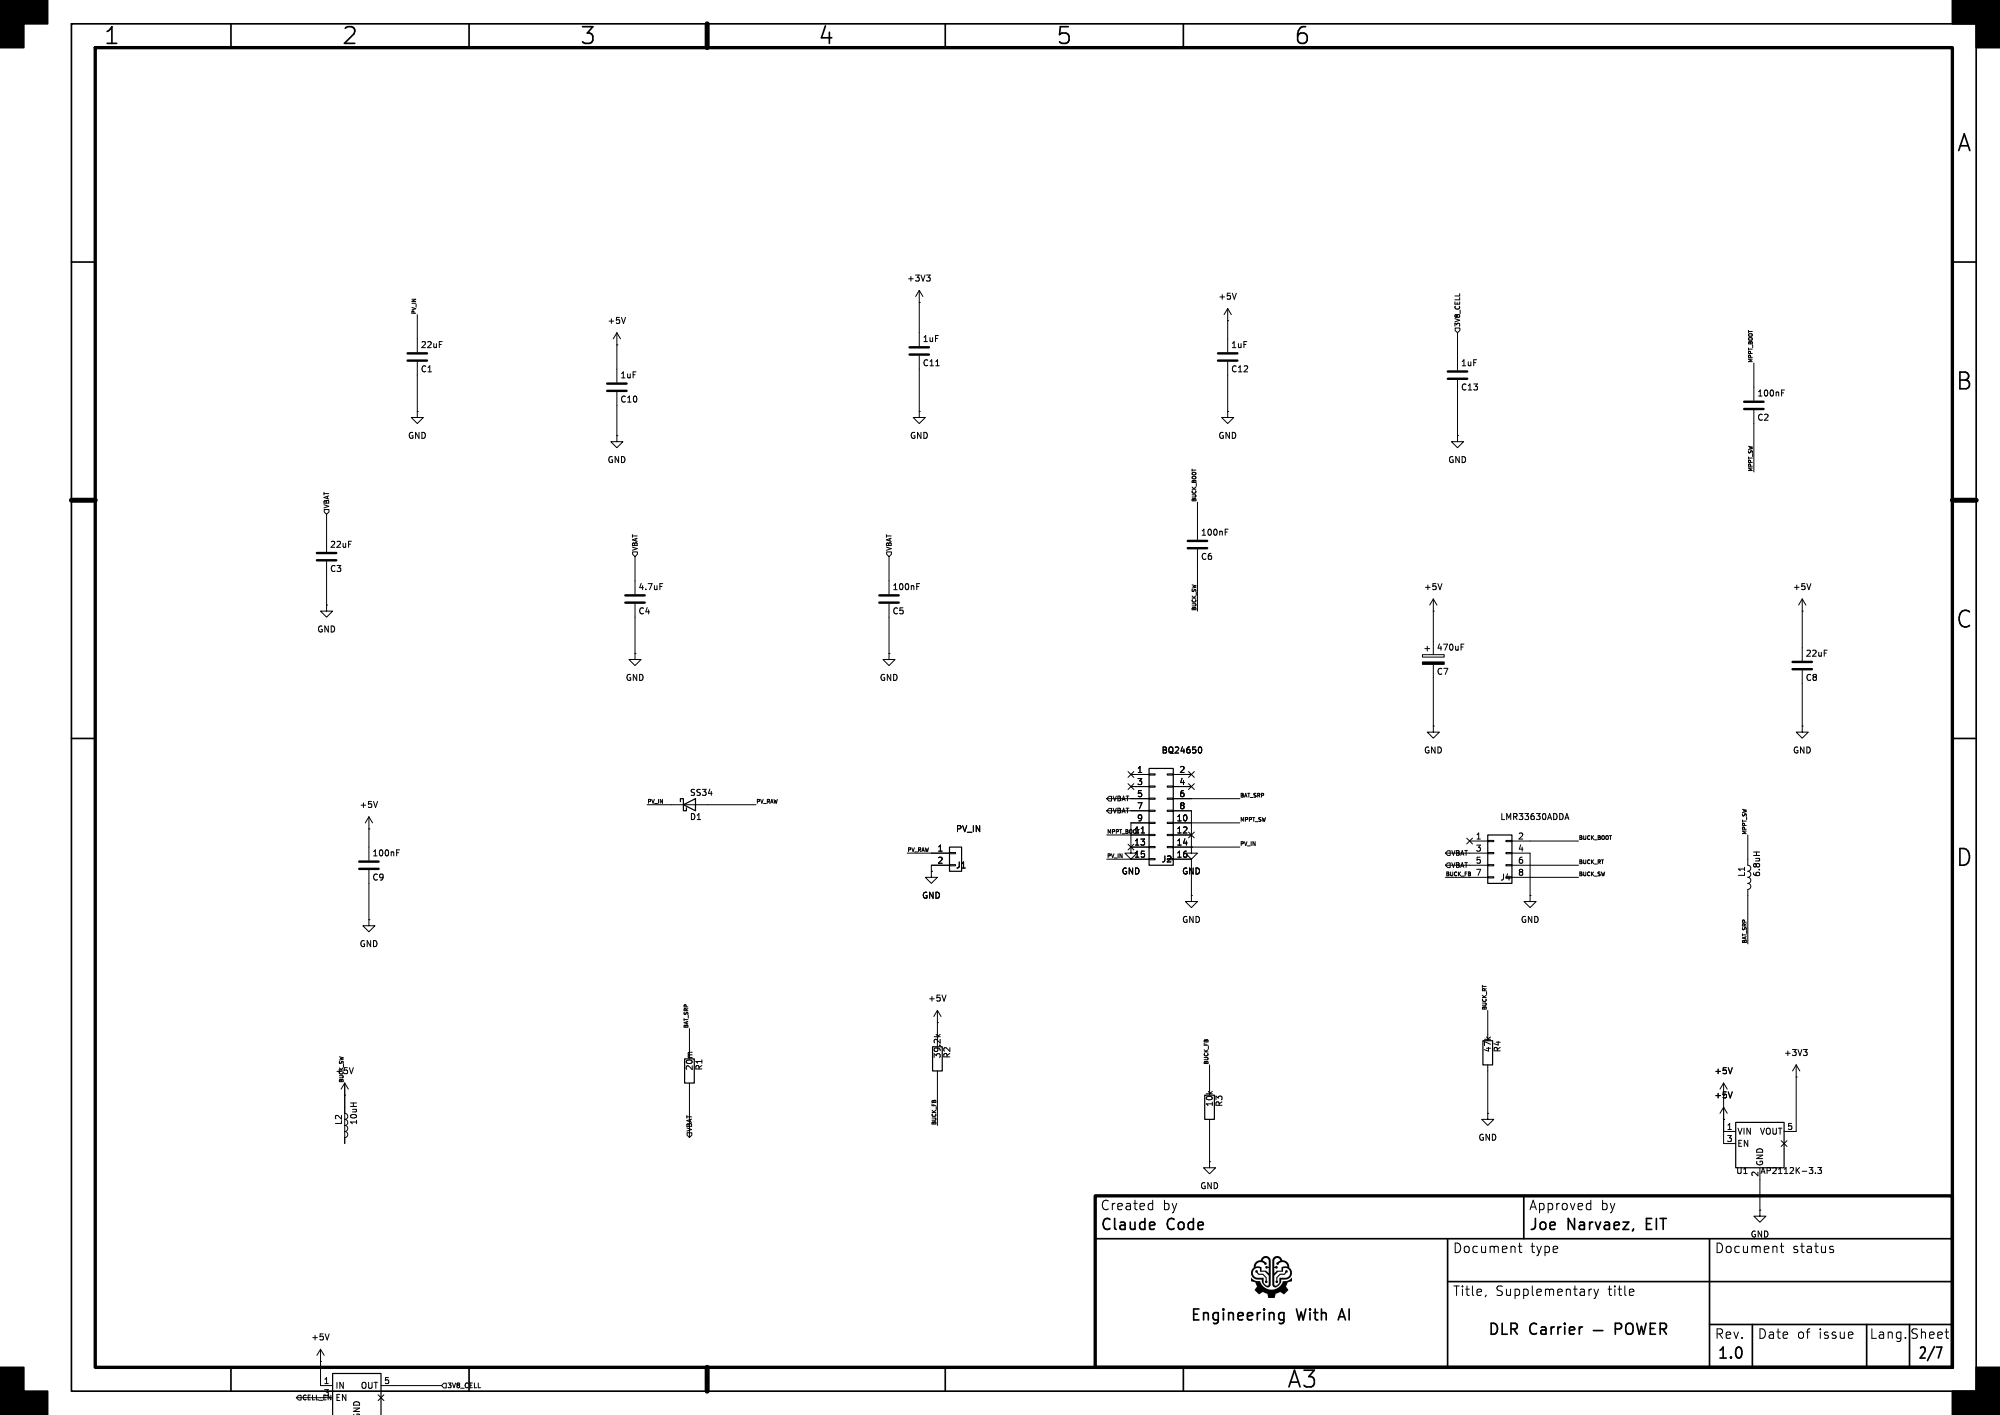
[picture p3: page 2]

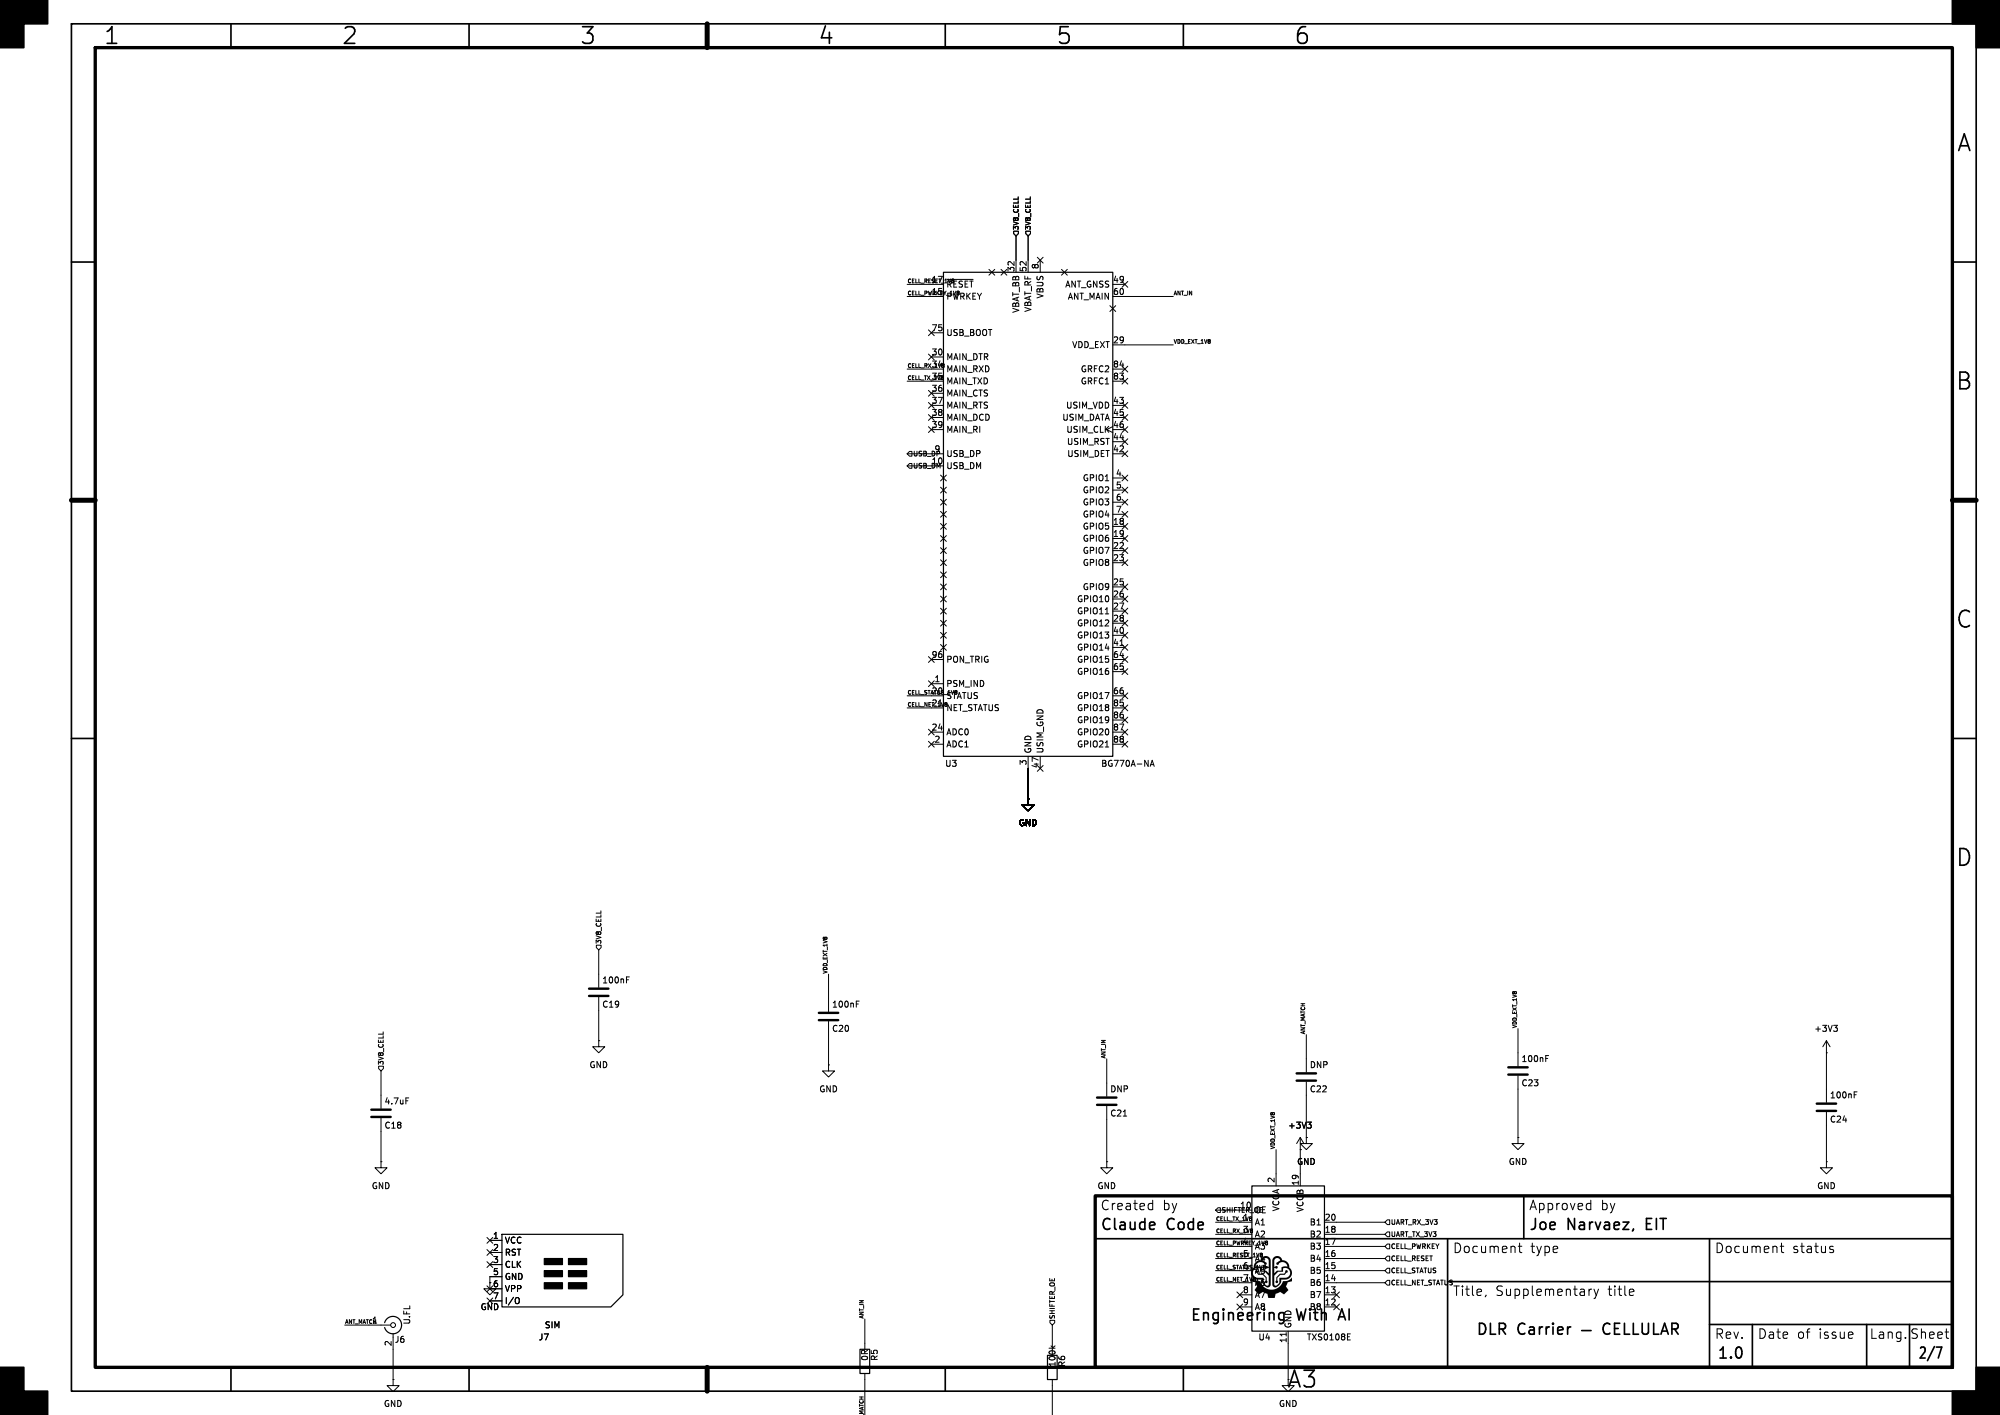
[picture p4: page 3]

Claude Code

VCC 1 RST 2 CLK 3 GND 5 VPP 6

CELL_STATUS_1V8 CELL_RESET_1V8

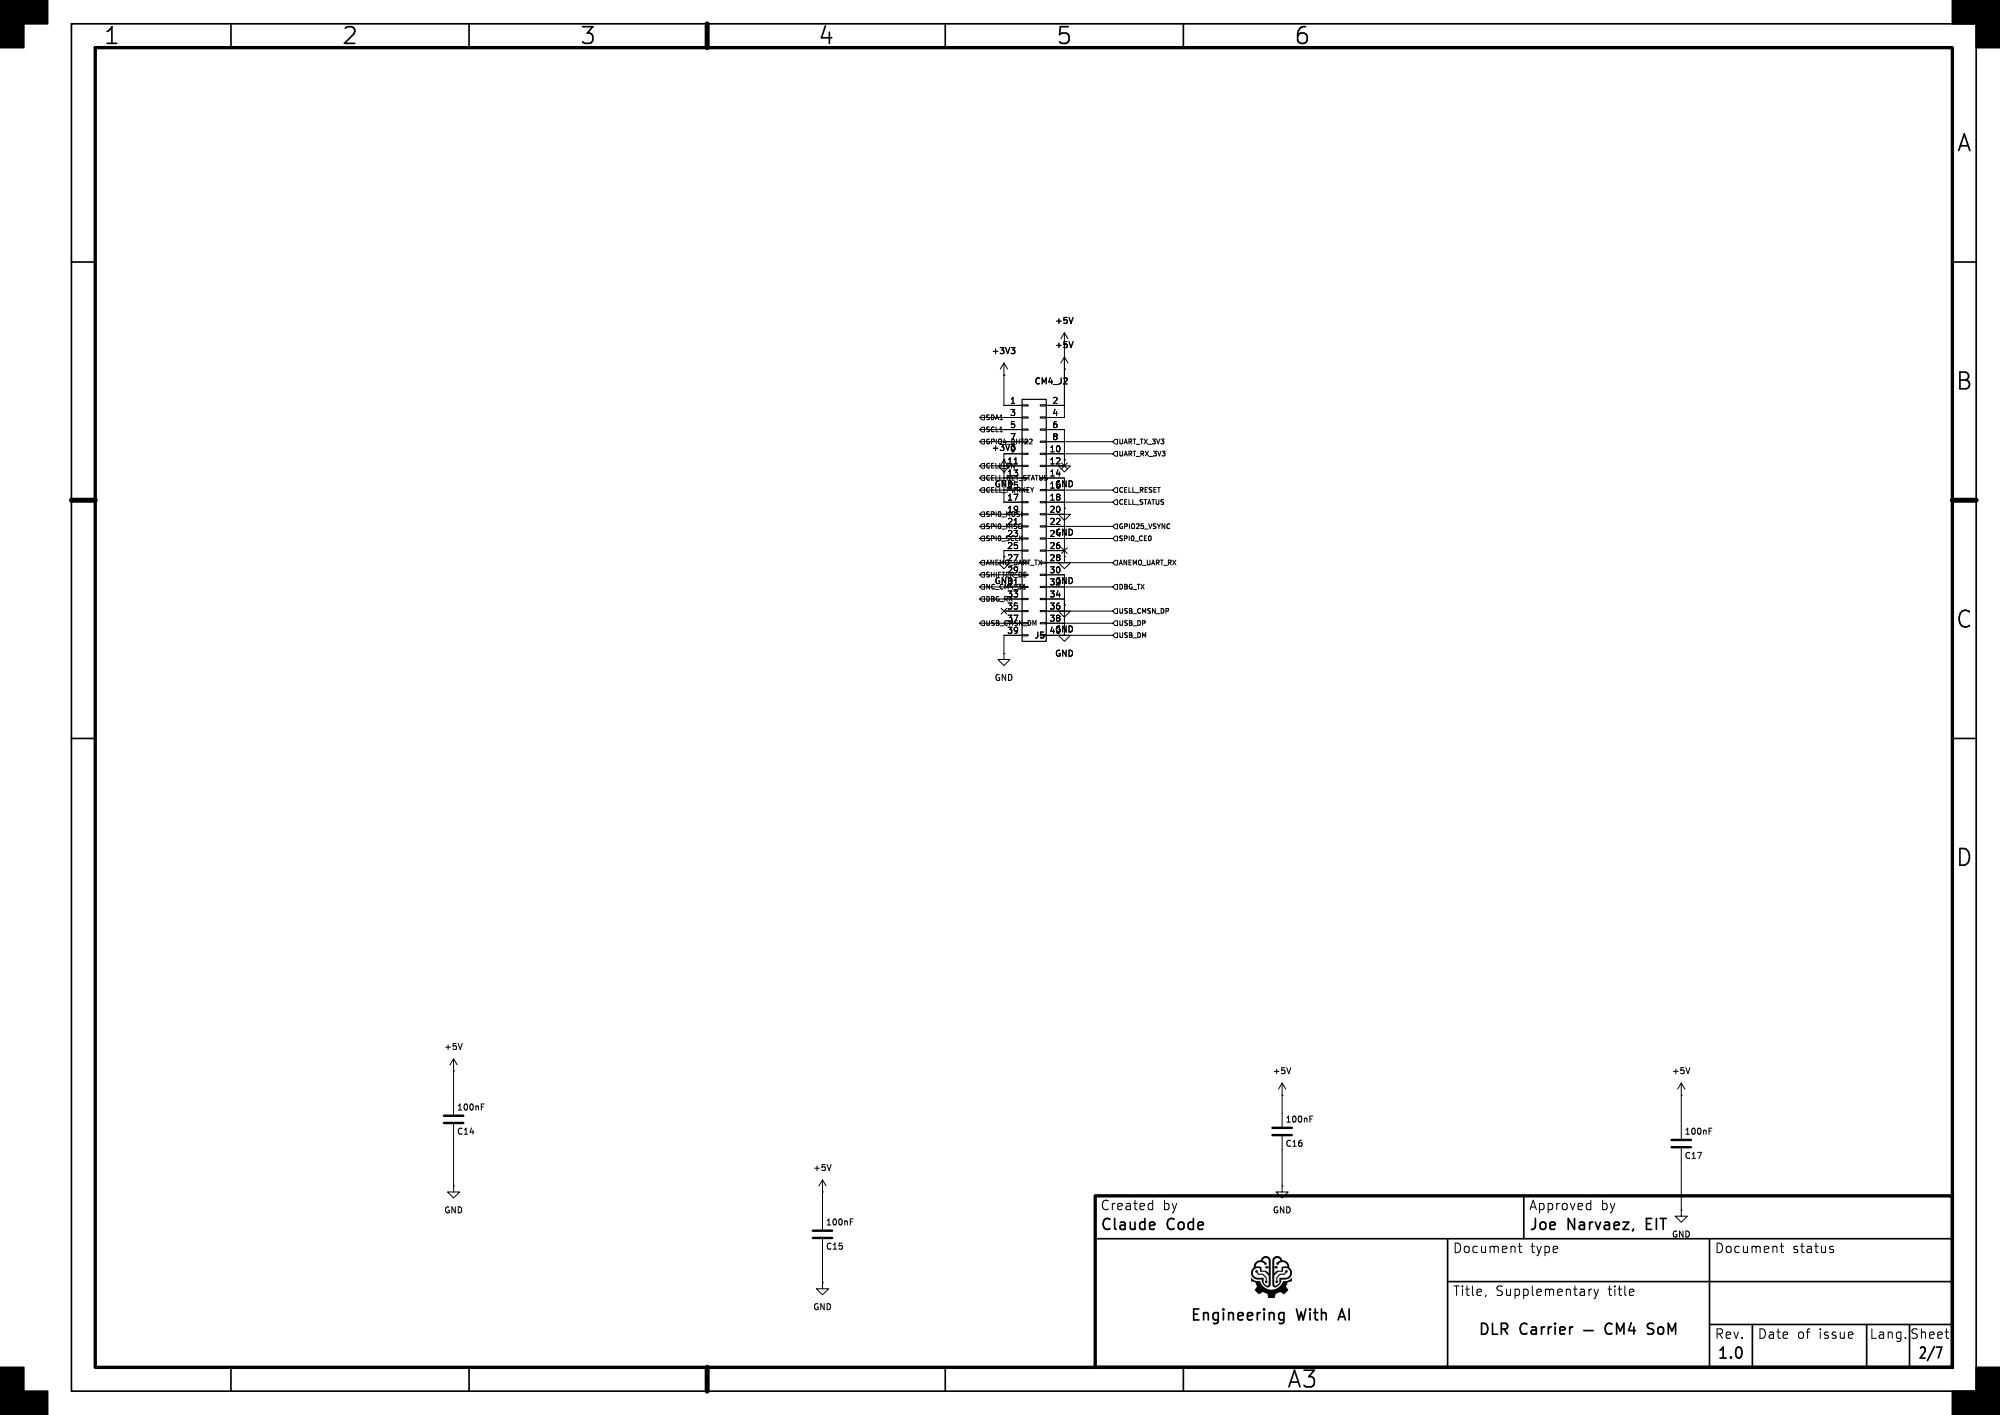
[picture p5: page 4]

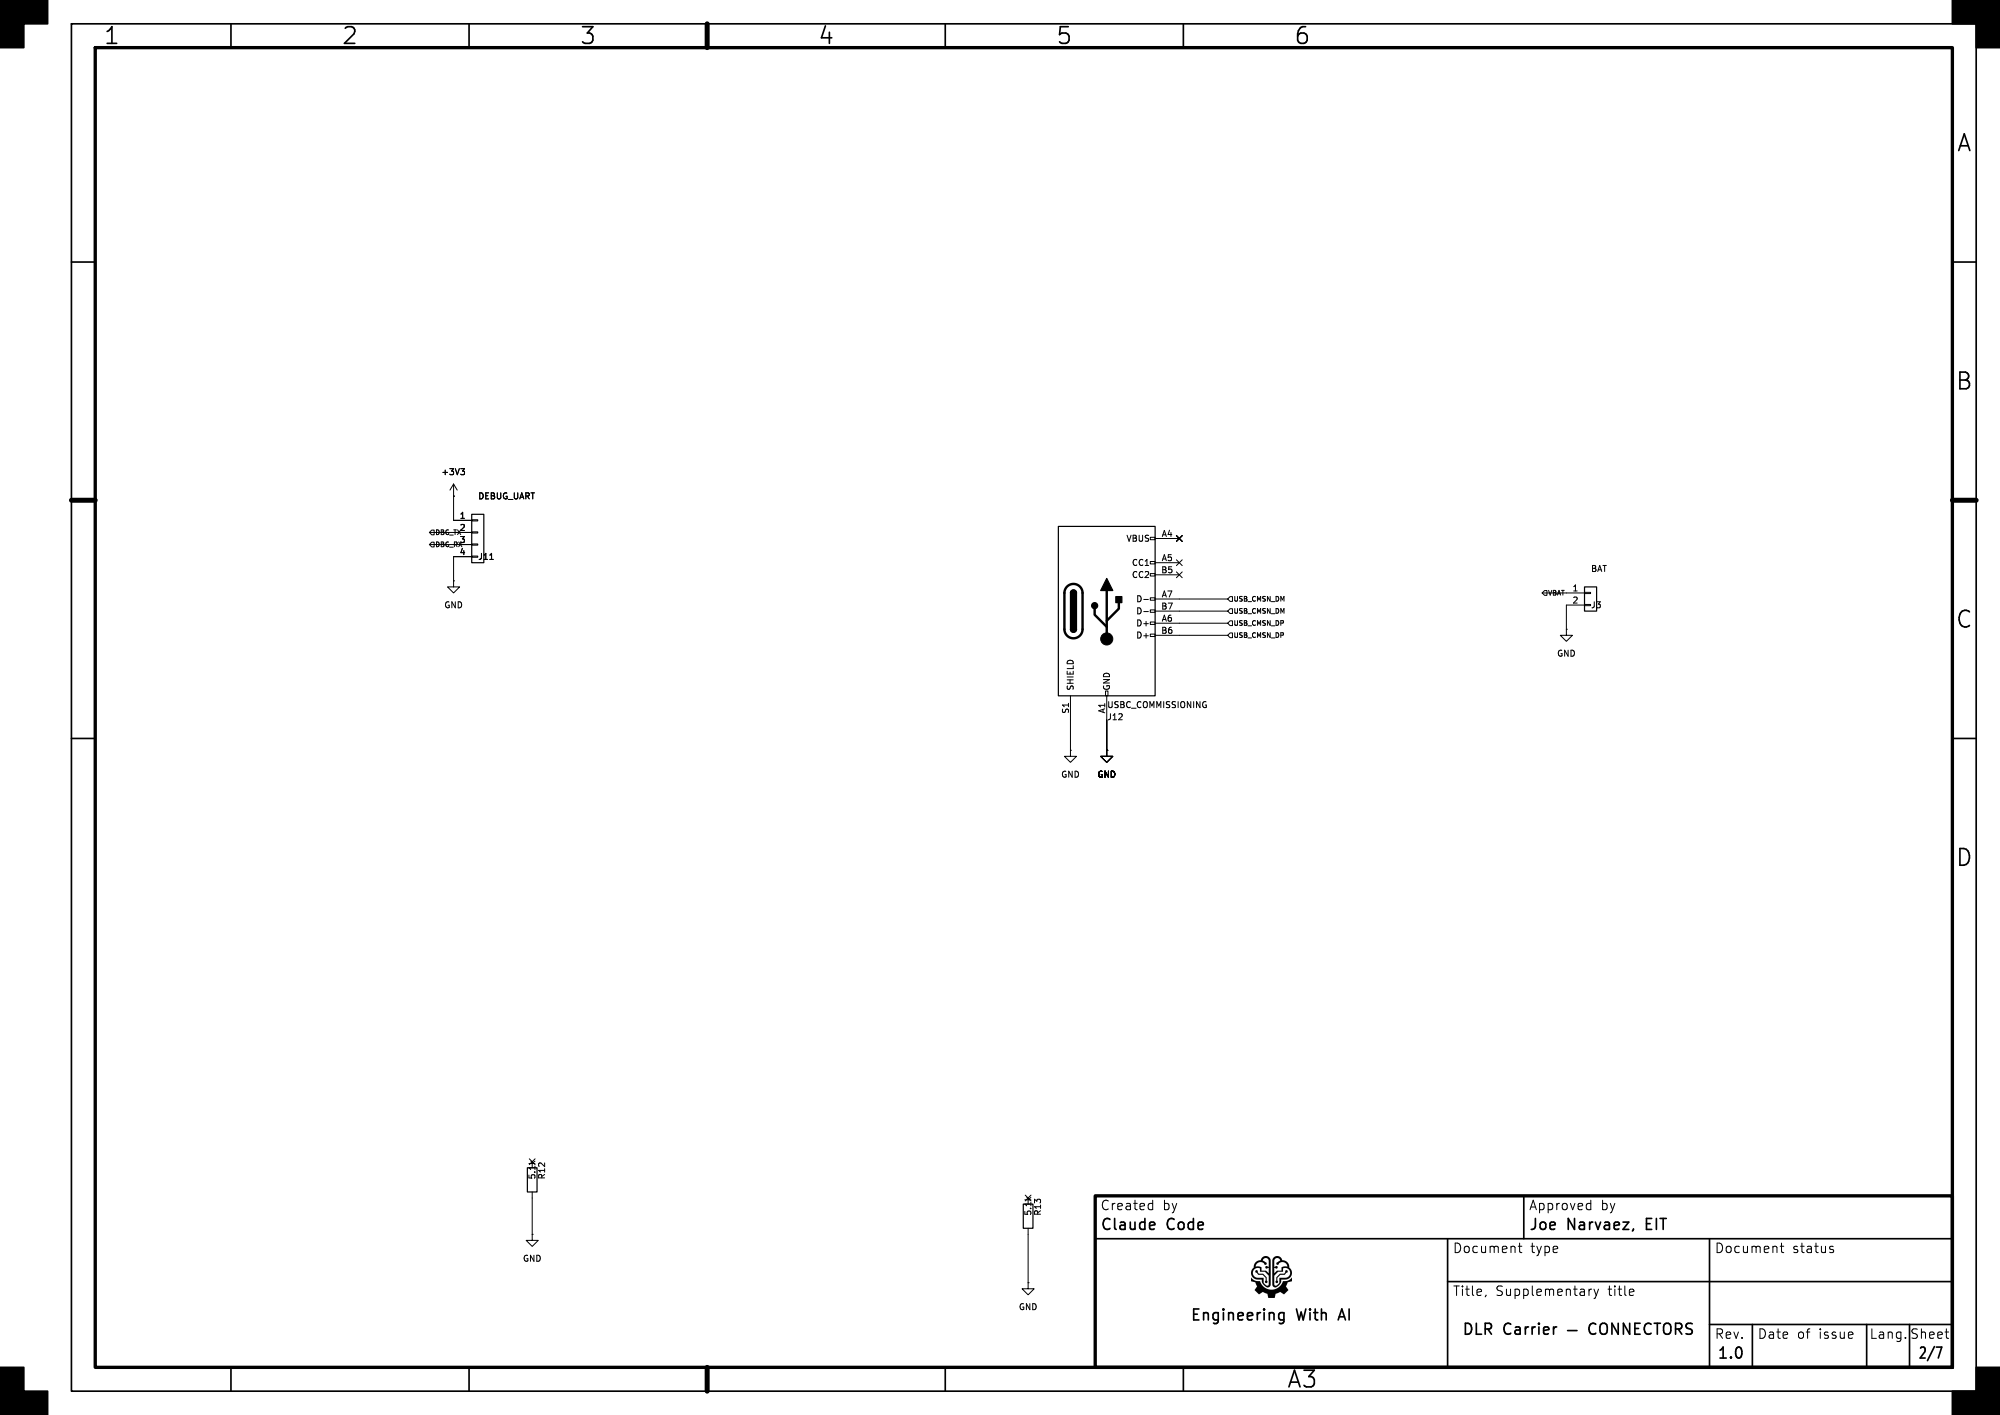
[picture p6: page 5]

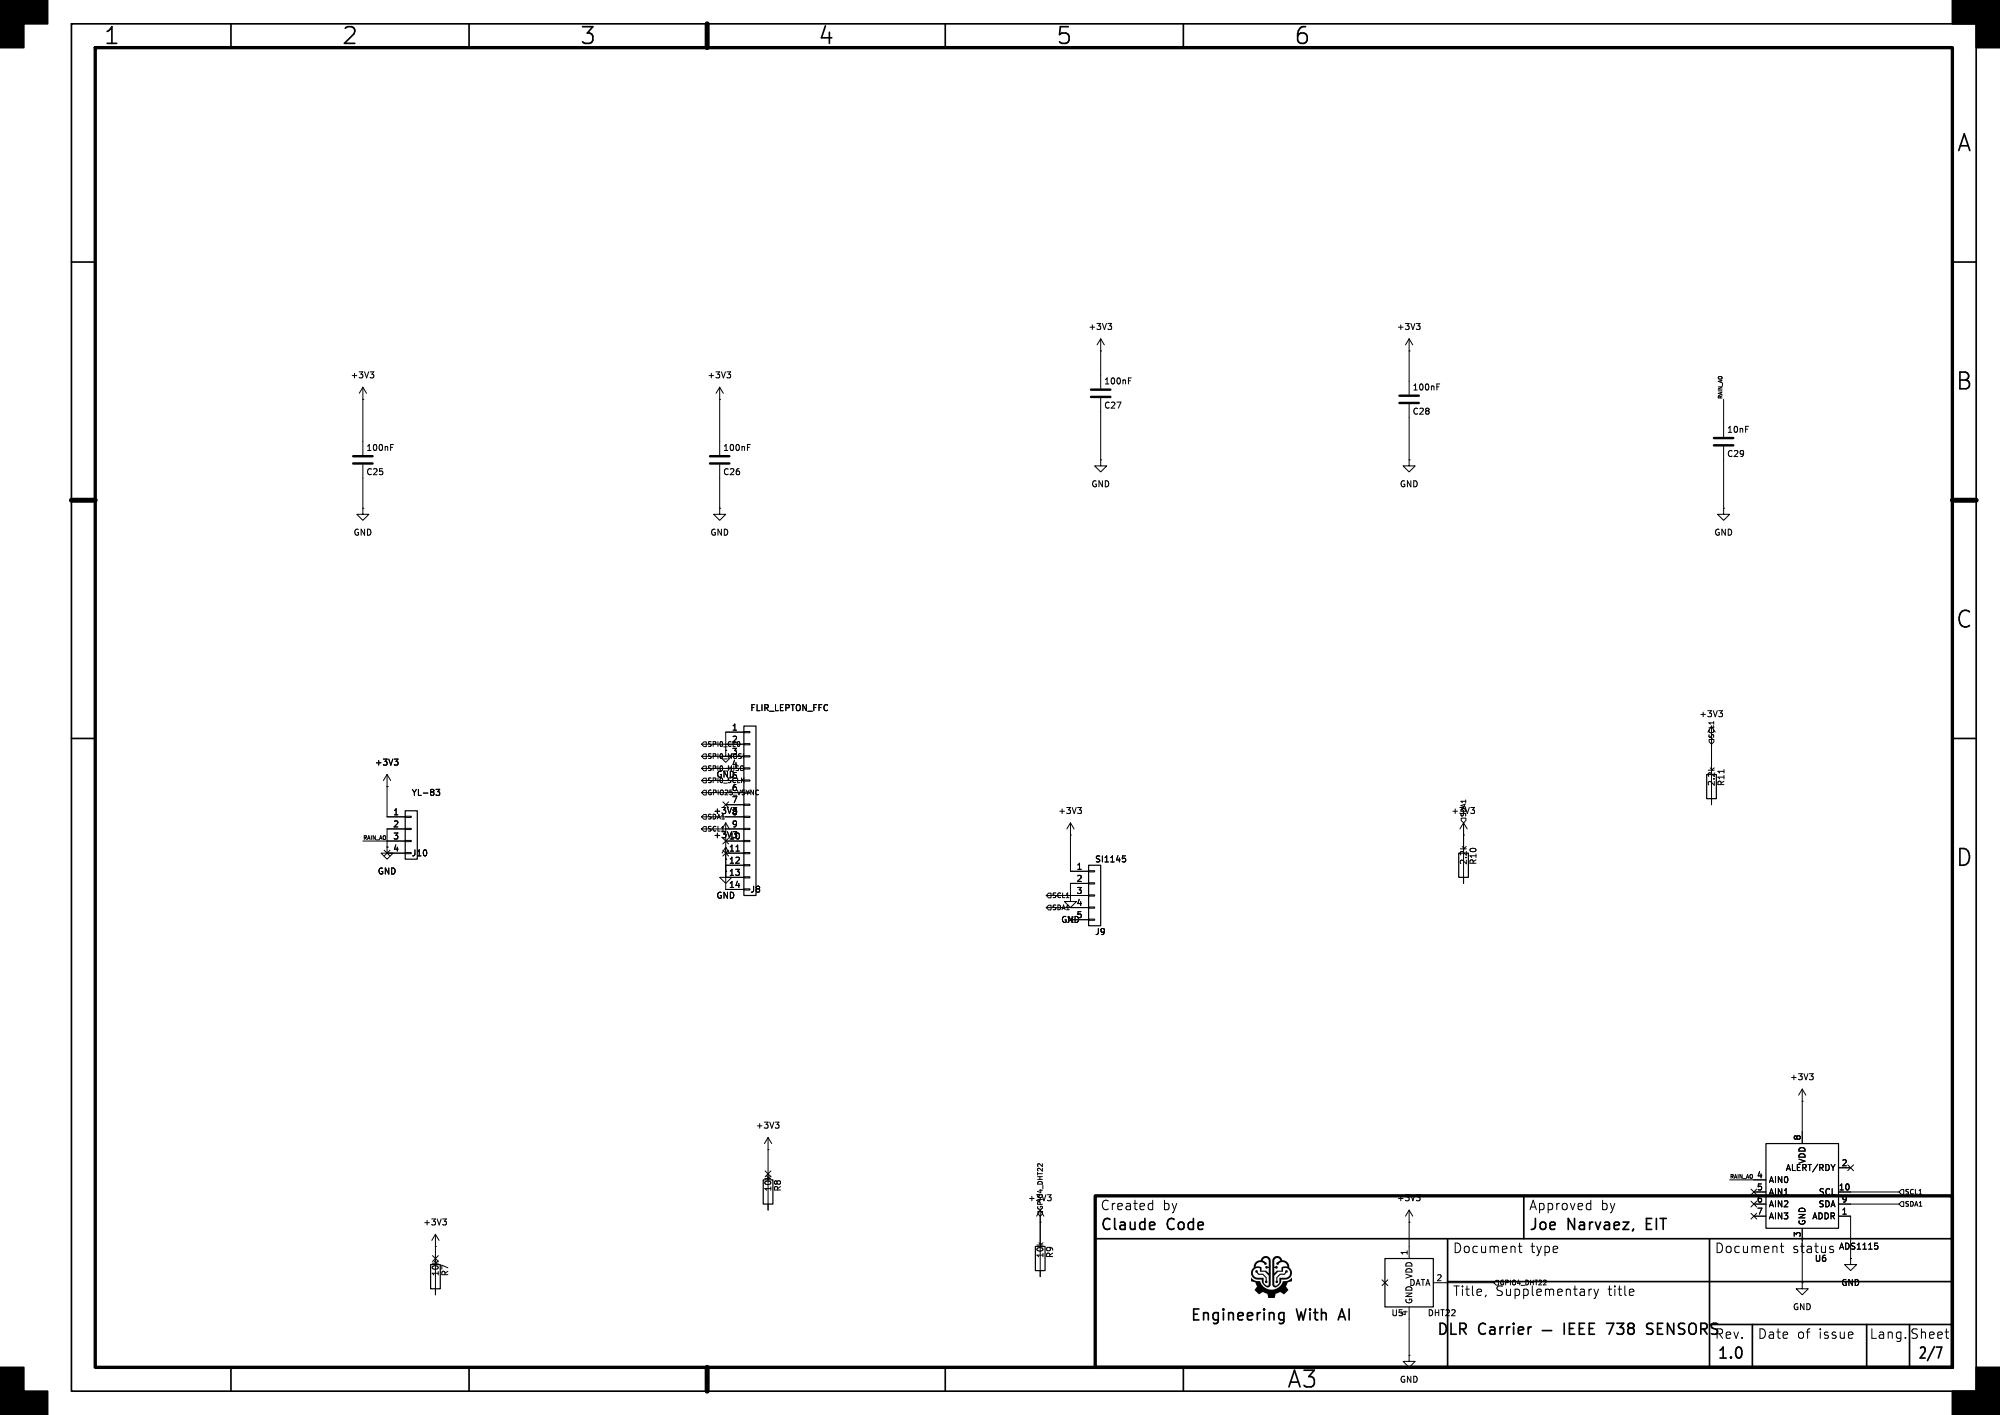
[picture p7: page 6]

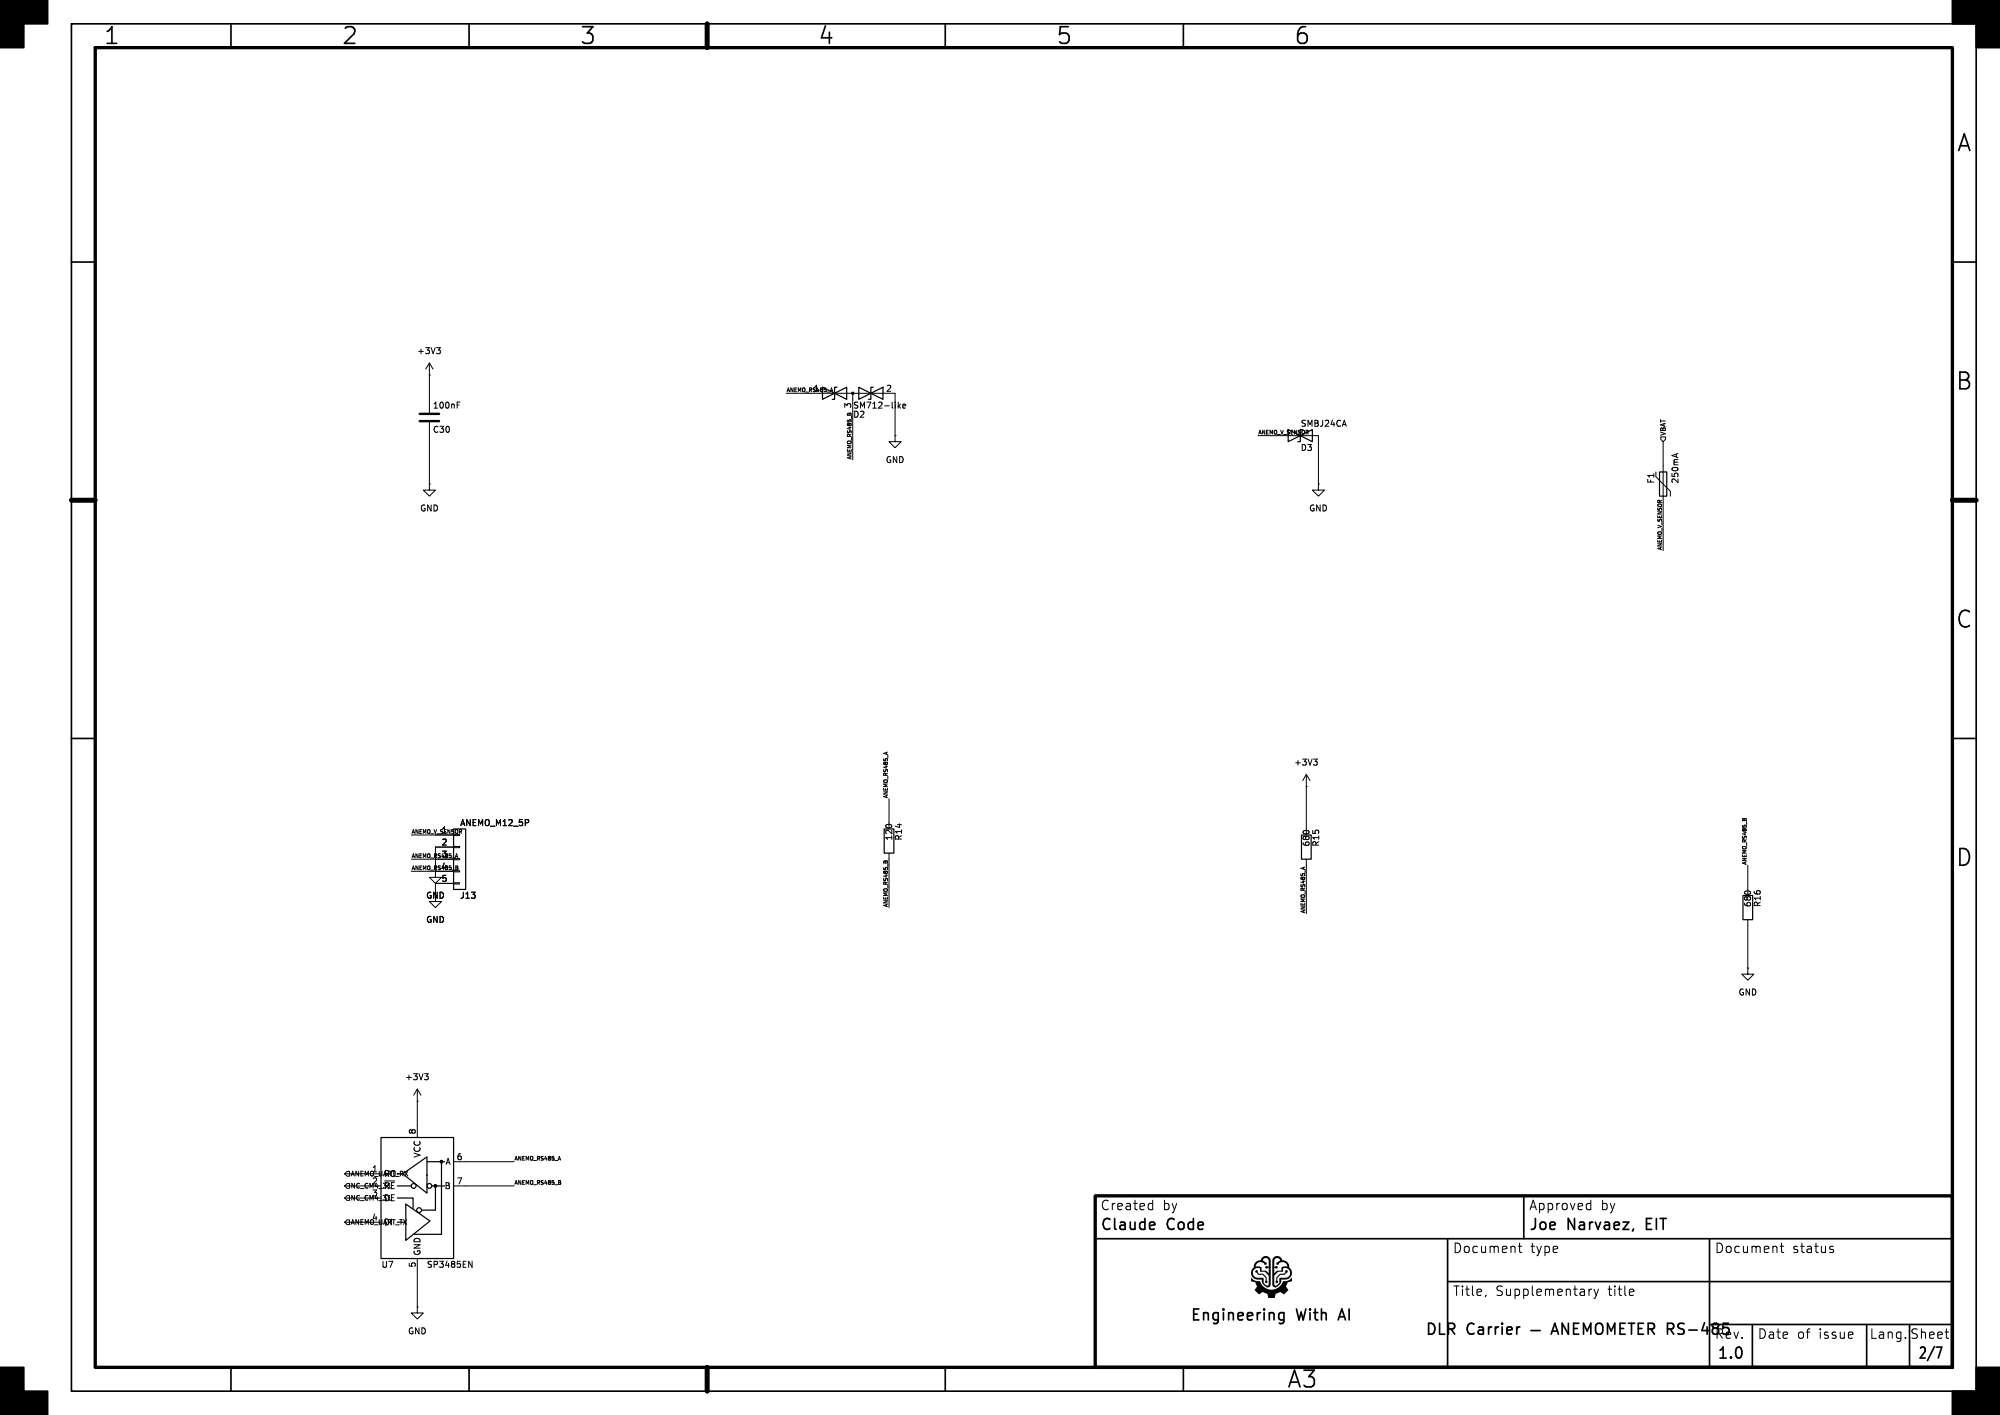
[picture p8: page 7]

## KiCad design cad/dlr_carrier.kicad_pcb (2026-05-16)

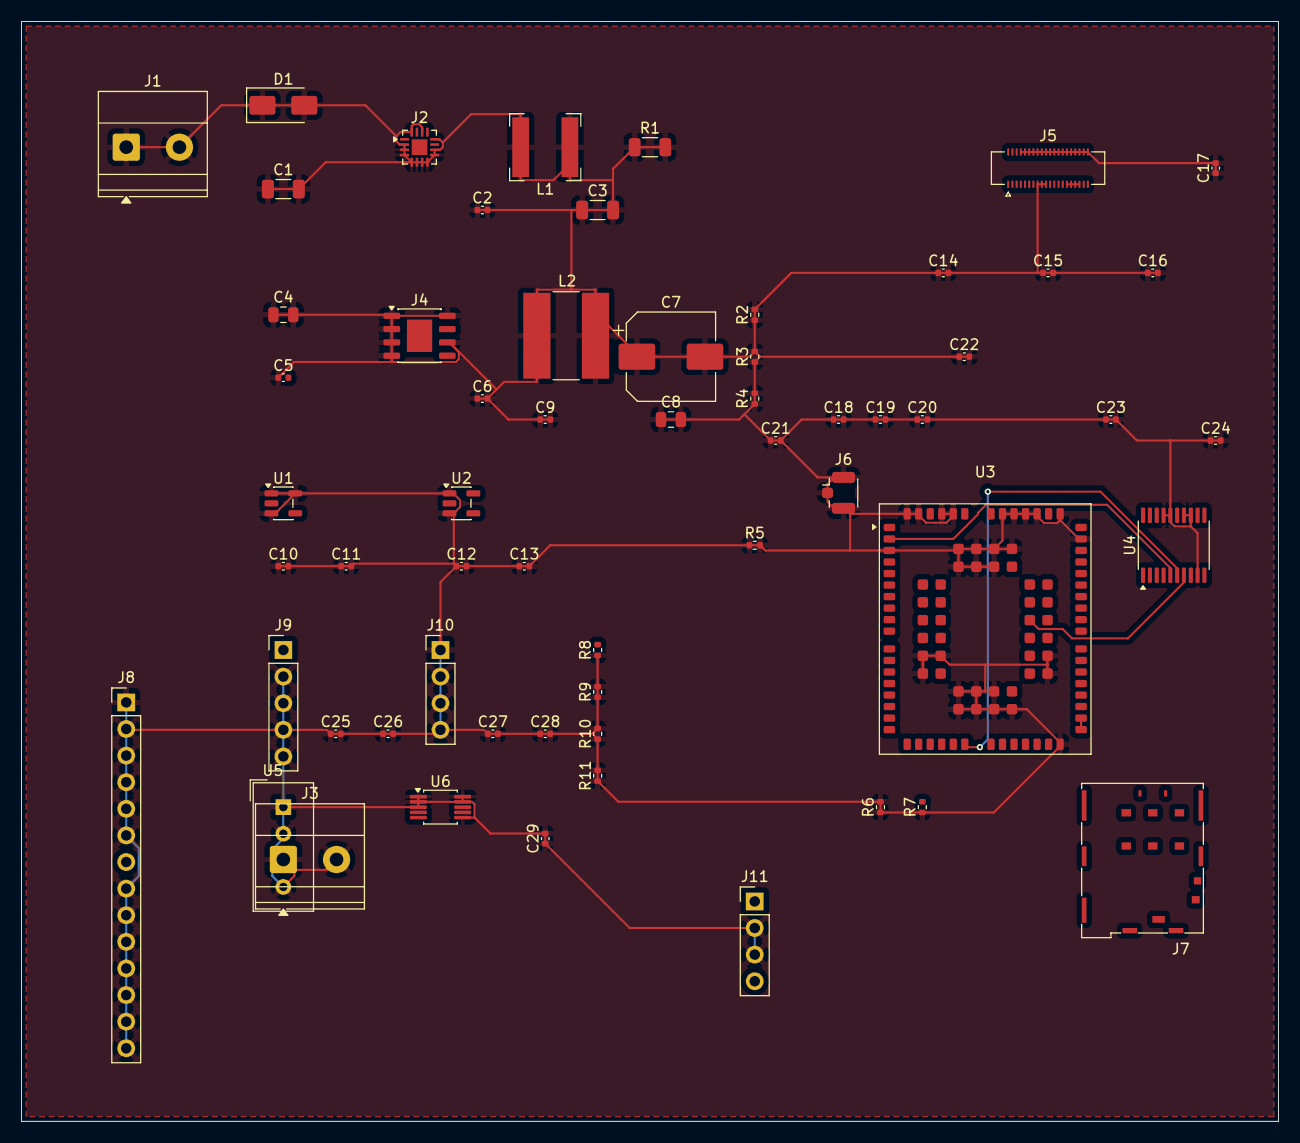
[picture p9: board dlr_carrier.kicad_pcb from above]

Board: 2 copper layers, 120.0 x 105.0 mm, 60 parts (0 on the bottom side), 9 nets.

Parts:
C1, C3: 22uF; C_1206_3216Metric
C2, C5, C6, C9, C14, C15, C16, C17, C19, C20, C23, C24, C25, C26, C27, C28: 100nF; C_0402_1005Metric
C4: 4.7uF; C_0805_2012Metric
C7: 470uF; CP_Elec_8x10
C8: 22uF; C_0805_2012Metric
C10, C11, C12, C13: 1uF; C_0402_1005Metric
C18: 4.7uF; C_0402_1005Metric
C21, C22: DNP; C_0402_1005Metric
C29: 10nF; C_0402_1005Metric
D1: SS34; D_SMA
J1: PV_IN; TerminalBlock_Phoenix_MKDS-1,5-2-5.08_1x02_P5.08mm_Horizont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
J2: BQ24650; HVQFN-16-1EP_3x3mm_P0.5mm_EP1.5x1.5mm
J3: BAT; TerminalBlock_Phoenix_MKDS-1,5-2-5.08_1x02_P5.08mm_Horizont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
J4: LMR33630ADDA; HSOP-8-1EP_3.9x4.9mm_P1.27mm_EP2.41x3.1mm
J5: CM4_J2; Hirose_DF40HC(3.0)-40DS-0.4V_2x20_P0.4mm
J6: U.FL; U.FL_Hirose_U.FL-R-SMT-1_Vertical
J7: SIM; microSIM_JAE_SF53S006VCBR2000
J8: FLIR_LEPTON; PinHeader_1x14_P2.54mm_Vertical
J9: SI1145; PinHeader_1x05_P2.54mm_Vertical
J10: YL-83; PinHeader_1x04_P2.54mm_Vertical
J11: DEBUG_UART; PinHeader_1x04_P2.54mm_Vertical
L1: 6.8uH; L_Bourns-SRN6028
L2: 10uH; L_Bourns-SRN8040_8x8.15mm
R1: 20m; R_1206_3216Metric
R2: 39.2k; R_0402_1005Metric
R3, R7, R8, R9: 10k; R_0402_1005Metric
R4: 47k; R_0402_1005Metric
R5: 0R; R_0402_1005Metric
R6: 100k; R_0402_1005Metric
R10, R11: 2.2k; R_0402_1005Metric
U1: AP2112K-3.3; SOT-23-5
U2: LP5907MFX-3.8; SOT-23-5
U3: BG770A-NA; Quectel_BG95
U4: TXS0108E; TSSOP-20_4.4x6.5mm_P0.65mm
U5: DHT22; Aosong_DHT11_5.5x12.0_P2.54mm
U6: ADS1115; MSOP-10_3x3mm_P0.5mm

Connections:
+3V3: C1.1, C1.2, C2.1, C2.2, C3.1, C3.2, C4.1, C4.2, C5.1, C6.1, C6.2, C7.1, C7.2, C8.1, C8.2, C9.1, C9.2, C10.1, C10.2, C11.1, C11.2, C12.1, C12.2, C13.1, C13.2, C14.1, C14.2, C15.1, C15.2, C16.1, C16.2, C17.1, C17.2, C18.1, C18.2, C19.1, C19.2, C20.1, C20.2, C21.1, C21.2, C22.1, C22.2, C23.1, C23.2, C24.1, C24.2, C25.1, C25.2, C26.1, C26.2, C27.1, C27.2, C28.1, C28.2, C29.1, C29.2, D1.1 (K), D1.2 (A), J1.1, J1.2, J2.2, J2.3, J2.4, J2.5, J2.6, J2.7, J2.8, J2.9, J2.10, J2.12, J2.14, J2.16, J3.1, J3.2, J4.1, J4.2, J4.3, J4.4, J4.6, J4.8, J5.1, J5.3, J5.6, J5.8, J5.9, J5.10, J5.12, J5.13, J5.14, J5.15, J5.16, J5.17, J5.18, J5.19, J5.20, J5.21, J5.22, J5.24, J5.26, J5.27, J5.28, J5.29, J5.30, J5.31, J5.32, J5.33, J5.34, J5.35, J5.36, J5.37, J5.38, J5.40, J6.1 (In), J6.2 (Ext), J8.1, J8.2, J8.3, J8.4, J8.5, J8.6, J8.8, J8.9, J8.10, J8.11, J8.12, J8.13, J8.14, J9.2, J9.3, J9.4, J9.5, J10.1, J10.2, J10.3, J10.4, J11.2, J11.3, L1.1, L1.2, L2.1, L2.2, R1.1, R1.2, R2.1, R2.2, R3.1, R3.2, R4.1, R4.2, R5.1, R5.2, R6.1, R6.2, R7.1, R8.1, R9.1, R9.2, R10.1, R10.2, R11.1, R11.2, U1.1 (VIN), U1.3 (EN), U1.5 (VOUT), U2.1 (IN), U2.3 (EN), U3.3 (GND), U3.31 (GND), U3.48 (GND), U3.50 (GND), U3.52 (VBAT_RF), U3.53 (VBAT_RF), U3.54 (GND), U3.55 (GND), U3.58 (GND), U3.59 (GND), U3.61 (GND), U3.62 (GND), U3.67 (GND), U3.68 (GND), U3.69 (GND), U3.70 (GND), U3.71 (GND), U3.72 (GND), U3.73 (GND), U3.74 (GND), U3.79 (GND), U3.80 (GND), U3.81 (GND), U3.82 (GND), U3.87 (GPIO20), U3.89 (GND), U3.90 (GND), U3.91 (GND), U3.100 (GND), U3.101 (GND), U3.102 (GND), U4.9 (A8), U4.13 (B7), U4.14 (B6), U4.16 (B4), U4.17 (B3), U5.1 (VDD), U5.2 (DATA), U5.4 (GND), U6.1 (ADDR), U6.2 (ALERT/RDY), U6.3 (GND), U6.6 (AIN2), U6.9 (SDA), U6.10 (SCL)
/CELL_NET_STATUS: J5.25, U4.18 (B2)
/CELL_PWRKEY: J5.23, U4.15 (B5)
/CELL_PWRKEY_1V8: U3.24 (ADC0), U4.6 (A5)
/CELL_RESET_1V8: U3.2 (ADC1), U4.5 (A4)
/CELL_RX_1V8: U3.96 (PON_TRIG), U4.7 (A6)
/CELL_STATUS_1V8: U3.75 (USB_BOOT), U4.4 (A3)
/DBG_RX: J5.5, J11.1
unnamed: U3.32 (VBAT_BB), U3.33 (VBAT_BB)

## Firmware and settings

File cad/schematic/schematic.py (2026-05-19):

"""DLR carrier schematic generator — block-aware placement, label-based connectivity.

Reads cad/dlr_carrier.net, classifies each component into a block (power, som,
cellular, sensors, connectors, misc), places each block's components in a
sub-grid within the block's region defined in layout_spec.yaml. Inter-block
connectivity is preserved through labels and power symbols.
"""

import contextlib
import math
from pathlib import Path
from typing import Final

import kicad_sch_api as ksa
import sexpdata
import yaml

LAYOUT_SPEC_PATH = Path("cad/layout_spec.yaml")
NETLIST_PATH = Path("cad/dlr_carrier.net")
SCHEMATIC_PATH = "cad/dlr_carrier.kicad_sch"

LIB_BY_PART: Final = {
    "C": "Device",
    "C_Polarized": "Device",
    "R": "Device",
    "L": "Device",
    "D_Schottky": "Device",
    "D_TVS": "Device",
    "D_TVS_Dual_AAC": "Device",
    "Polyfuse": "Device",
    "Conn_Coaxial": "Connector",
    "SIM_Card": "Connector",
    "AP2112K-3.3": "Regulator_Linear",
    "LP5907MFX-3.3": "Regulator_Linear",
    "BG95-M1": "RF_GSM",
    "TXS0108EPW": "Logic_LevelTranslator",
    "ADS1115IDGS": "Analog_ADC",
    "DHT11": "Sensor",
    "SP3485EN": "Interface_UART",
    "USB_C_Receptacle_USB2.0_14P": "Connector",
}

# Component value -> block (catches all uniquely-named ICs and connectors)
VALUE_TO_BLOCK: Final = {
    # power
    "PV_IN": "power",
    "SS34": "power",
    "BQ24650": "power",
    "LMR33630ADDA": "power",
    "AP2112K-3.3": "power",
    "LP5907MFX-3.8": "power",
    # som
    "CM4_J2": "som",
    # cellular
    "BG770A-NA": "cellular",
    "TXS0108E": "cellular",
    "U.FL": "cellular",
    "SIM": "cellular",
    # sensors
    "FLIR_LEPTON": "sensors",
    "FLIR_LEPTON_FFC": "sensors",
    "DHT22": "sensors",
    "SI1145": "sensors",
    "YL-83": "sensors",
    "ADS1115": "sensors",
    # connectors
    "BAT": "connectors",
    "DEBUG_UART": "connectors",
    "USBC_COMMISSIONING": "connectors",
    # anemometer
    "SP3485EN": "anemometer",
    "ANEMO_M12_5P": "anemometer",
    "SM712-like": "anemometer",
    "SMBJ24CA": "anemometer",
}

# Block-specific nets (for classifying passives that don't have unique values)
BLOCK_NETS: Final = {
    "power": {
        "PV_IN",
        "PV_RAW",
        "VBAT",
        "BAT_SRP",
        "MPPT_SW",
        "MPPT_BOOT",
        "BUCK_SW",
        "BUCK_BOOT",
        "BUCK_FB",
        "BUCK_RT",
    },
    "cellular": {
        "3V8_CELL",
        "VDD_EXT_1V8",
        "ANT_IN",
        "ANT_MATCH",
        "CELL_PWRKEY",
        "CELL_RESET",
        "CELL_STATUS",
        "CELL_NET_STATUS",
        "CELL_TX_1V8",
        "CELL_RX_1V8",
        "CELL_PWRKEY_1V8",
        "CELL_RESET_1V8",
        "CELL_STATUS_1V8",
        "CELL_NET_1V8",
    },
    "sensors": {
        "RAIN_AO",
        "GPIO4_DHT22",
        "GPIO25_VSYNC",
    },
    "connectors": {"DBG_TX", "DBG_RX"},
    "anemometer": {
        "ANEMO_RS485_A",
        "ANEMO_RS485_B",
        "ANEMO_UART_TX",
        "ANEMO_UART_RX",
        "ANEMO_DE",
        "ANEMO_V_SENSOR",
        "ANEMO_SHIELD",
    },
}

POWER_SYMBOL_BY_NET: Final = {
    "GND": "power:GND",
    "5V_RAIL": "power:+5V",
    "3V3": "power:+3V3",
}


def _real_pin_position(comp, pin_num: str):
    """Pin position in sheet coords, fixing kicad-sch-api's y-inversion bug.

    kicad-sch-api computes pin_y = sym_y + pin_offset_y, but KiCad's actual
    rendering uses pin_y = sym_y - pin_offset_y (symbol coords are +y up,
    sheet coords are +y down). Reflect ksa's reported y around sym_y to get
    the position KiCad will actually draw the pin at.

    Only valid for unrotated symbols (rotation=0). All components produced
    by _place_one are placed unrotated, so this assumption holds.
    """
    pos = comp.get_pin_position(pin_num)
    if not pos:
        return None
    sym_y = comp.position.y
    return type(pos)(pos.x, 2 * sym_y - pos.y)


def _resolve_lib(part_name: str) -> str:
    if part_name in LIB_BY_PART:
        return LIB_BY_PART[part_name]
    if part_name.startswith("Conn_01x") or part_name.startswith("Conn_02x"):
        return "Connector_Generic"
    raise ValueError(f"Unknown lib for part {part_name!r}")


def _parse_netlist(path: Path) -> tuple[list[dict], list[dict]]:  # noqa: C901
    """Extract components and nets from a SKiDL-generated kicad netlist."""
    data = sexpdata.loads(path.read_text())
    components, nets = [], []

    def s(node) -> str:
        return str(node[0]) if isinstance(node, list) and node else ""

    def find_section(root, key) -> list:
        if isinstance(root, list):
            if s(root) == key:
                return root
            for child in root:
                r = find_section(child, key)
                if r:
                    return r
        return []

    for comp in find_section(data, "components")[1:]:
        info: dict = {}
        for field in comp[1:]:
            tag = s(field)
            if tag == "ref":
                info["ref"] = field[1]
            elif tag == "value":
                info["value"] = field[1]
            elif tag == "footprint":
                info["footprint"] = field[1]
            elif tag == "libsource":
                for sub in field[1:]:
                    if s(sub) == "part":
                        info["part"] = sub[1]
            elif tag == "fields":
                # Look for SKiDL's "SKiDL Line" field — source file pinpoints block
                for sub in field[1:]:
                    if s(sub) == "field":
                        # field structure: (field (name "SKiDL Line") "power.py:17")
                        for inner in sub[1:]:
                            if (
                                isinstance(inner, list)
                                and s(inner) == "name"
                                and len(inner) > 1
                                and inner[1] == "SKiDL Line"
                                and len(sub) > 2
                                and isinstance(sub[2], str)
                            ):
                                # field structure: (field (name "SKiDL Line") "power.py:17")
                                info["source"] = sub[2]
        if info.get("ref"):
            components.append(info)

    for net in find_section(data, "nets")[1:]:
        info = {"name": "", "nodes": []}
        for field in net[1:]:
            tag = s(field)
            if tag == "name":
                info["name"] = field[1]
            elif tag == "node":
                node = {}
                for sub in field[1:]:
                    if s(sub) == "ref":
                        node["ref"] = sub[1]
                    elif s(sub) == "pin":
                        node["pin"] = sub[1]
                    elif s(sub) == "pintype":
                        node["pintype"] = sub[1]
                if node:
                    info["nodes"].append(node)
        if info["name"]:
            nets.append(info)
    return components, nets


def _comp_nets_index(nets: list[dict]) -> dict[str, set[str]]:
    """Build {ref: {net_name, ...}} for all components."""
    idx: dict[str, set[str]] = {}
    for net in nets:
        for node in net["nodes"]:
            idx.setdefault(node["ref"], set()).add(net["name"])
    return idx


SOURCE_FILE_TO_BLOCK: Final = {
    "power.py": "power",
    "som.py": "som",
    "cellular.py": "cellular",
    "sensors.py": "sensors",
    "connectors.py": "connectors",
    "anemometer.py": "anemometer",
    "model.py": "connectors",  # model.py's _build_battery_connector previously
}


def _classify(comp: dict, comp_nets: set[str]) -> str:
    """Assign component to a block by SKiDL source file, then value, then nets."""
    # Best signal: SKiDL records the source file in a field
    src = comp.get("source", "")
    for fname, block in SOURCE_FILE_TO_BLOCK.items():
        if fname in src:
            return block
    val = comp.get("value", "")
    if val in VALUE_TO_BLOCK:
        return VALUE_TO_BLOCK[val]
    scores = {
        b: sum(1 for n in comp_nets if n in nets) for b, nets in BLOCK_NETS.items()
    }
    best = max(scores, key=scores.get)
    if scores[best] > 0:
        return best
    if {"5V_RAIL", "3V3"} & comp_nets:
        return "power"
    return "misc"


def _grid_for_block(n: int, w: int, h: int) -> tuple[int, int, int]:
    """Choose (cols, cell_w, cell_h) so n components fit in w x h with even spacing."""
    if n == 0:
        return 1, w, h
    cols = max(1, min(n, math.ceil(math.sqrt(n * w / max(h, 1)))))
    rows = math.ceil(n / cols)
    cell_w = max(20, w // cols)
    cell_h = max(20, h // rows)
    return cols, cell_w, cell_h


BLOCK_TITLES: Final = {
    "power": "POWER",
    "som": "CM4 SoM",
    "cellular": "CELLULAR",
    "sensors": "IEEE 738 SENSORS",
    "connectors": "CONNECTORS",
    "anemometer": "ANEMOMETER RS-485",
    "misc": "MISC",
}


def _draw_block_frame(sch, block_name: str, region: dict) -> None:
    """Thin gray dashed border + title text for a functional block."""
    ox, oy = region["origin"]
    w, h = region["width"], region["height"]
    pad = 4  # frame padding so it doesn't crowd components
    gray = (128, 128, 128, 1.0)
    with contextlib.suppress(Exception):
        sch.add_rectangle(
            start=(ox - pad, oy - pad),
            end=(ox + w + pad, oy + h + pad),
            stroke_width=0.05,
            stroke_type="dash",
            stroke_color=gray,
        )
        title = BLOCK_TITLES.get(block_name, block_name.upper())
        sch.add_text(
            title,
            position=(ox, oy - pad - 3),
            size=2.0,
            bold=True,
            color=gray,
        )


# Components whose symbol body is much taller than typical (multi-unit / many-pin).
# Reserve a dedicated full-width row at the top of their block so their pin
# labels and body don't overflow into adjacent components.
TALL_COMPONENT_VALUES: Final = {"BG770A-NA", "CM4_J2"}
TALL_ROW_HEIGHT: Final = 110  # grid units — covers BG770A body (~80) + label margin


def _place_one(sch, comp: dict, gx: int, gy: int):
    """Instantiate a single component at (gx, gy)."""
    lib_id = f"{_resolve_lib(comp['part'])}:{comp['part']}"
    c = sch.components.add(
        lib_id, comp["ref"], comp.get("value", ""), position=(gx, gy)
    )
    if comp.get("footprint"):
        c.footprint = comp["footprint"]
    return c


def _place_block(sch, block_components: list[dict], region: dict) -> dict:
    """Place tall ICs in a dedicated top row, rest in a sub-grid below."""
    placed: dict = {}
    ox, oy = region["origin"]
    w, h = region["width"], region["height"]

    tall = [c for c in block_components if c.get("value") in TALL_COMPONENT_VALUES]
    rest = [c for c in block_components if c.get("value") not in TALL_COMPONENT_VALUES]

    rest_oy, rest_h = oy, h
    if tall:
        cell_w_t = w // len(tall)
        gy_t = oy + TALL_ROW_HEIGHT // 2
        for i, comp in enumerate(tall):
            gx = ox + i * cell_w_t + cell_w_t // 2
            placed[comp["ref"]] = _place_one(sch, comp, gx, gy_t)
        rest_oy = oy + TALL_ROW_HEIGHT
        rest_h = max(20, h - TALL_ROW_HEIGHT)

    n = len(rest)
    if n:
        cols, cw, ch = _grid_for_block(n, w, rest_h)
        for i, comp in enumerate(rest):
            row, col = divmod(i, cols)
            # Per-component (dx, dy) hash jitter breaks x- and y-coincidence
            # across the whole schematic. KiCad ERC falsely merges nets when
            # any two wires share an x or y, so wide entropy is needed to avoid
            # cascade merges. Prime moduli (17, 23) reduce structured collisions
            # vs round moduli that align with pin offsets like 2.54/3.81/5.08.
            h = abs(hash(comp["ref"]))
            dx = h % 17
            dy = (h // 17) % 23
            gx = ox + col * cw + cw // 2 + dx
            gy = rest_oy + row * ch + ch // 2 + dy
            placed[comp["ref"]] = _place_one(sch, comp, gx, gy)
    return placed


class PwrCounter:
    """Generates unique #PWR / #FLG references for power symbols."""

    def __init__(self):
        """Init counters."""
        self.n = 1
        self.flg = 1

    def pwr_ref(self) -> str:
        """Next unique #PWR ref."""
        ref = f"#PWR{self.n:03d}"
        self.n += 1
        return ref

    def flg_ref(self) -> str:
        """Next unique #FLG ref."""
        ref = f"#FLG{self.flg:03d}"
        self.flg += 1
        return ref


def _outward_direction(comp, pin_num: str) -> tuple[int, int]:
    """Direction the pin points outward from the symbol body (dx, dy in grid units).

    Uses the pin's own rotation attribute. Convention: kicad pin rotation 0
    means the pin LINE extends rightward INTO the symbol body, so the
    connection end (outer tip) is on the LEFT. Outward direction is the
    opposite of the pin line direction.
    """
    try:
        p = comp.get_pin(pin_num)
        if not p:
            return (-1, 0)
        rot = int(p.rotation) % 360
    except Exception:
        return (-1, 0)
    if rot == 0:
        return (-1, 0)  # pin points right into body -> outward left
    if rot == 180:
        return (1, 0)  # pin points left into body  -> outward right
    if rot == 90:
        return (0, 1)  # pin points up into body    -> outward down (+y in kicad = down)
    if rot == 270:
        return (0, -1)  # pin points down into body  -> outward up
    return (-1, 0)


def _net_jitter(net_name: str) -> tuple[int, int]:
    """Per-net x/y offset (0-2 grid) to break kicad's false-merge y/x coincidence bug."""
    h = abs(hash(net_name))
    return (h % 3, (h // 3) % 3)


NET_Y_MOD: Final = {"GND": 0, "5V_RAIL": 1, "3V3": 2}


def _power_symbol_y(net_name: str, base_y: int) -> int:
    """Snap a power symbol's y to a unique-per-net residue mod 4.

    KiCad ERC falsely merges nets when any two of their pins/symbols share
    a y-coordinate (anywhere on the sheet — not just adjacent). Forcing each
    net's symbols to land on a distinct y-mod-4 residue guarantees that two
    *different* power nets can never produce a pin at the same y, so the
    cross-net cascade can't trigger. Same-net symbols may share y, which is
    fine because they're supposed to be on the same net anyway.
    """
    target = NET_Y_MOD.get(net_name, 3)
    return base_y - (base_y % 4) + target


def _route_pin(sch, comp, pin_num: str, net_name: str, pwr: PwrCounter) -> None:
    """Stub a single pin — power symbol for power nets, NC marker for NC_*, label otherwise."""
    try:
        pin_pos_mm = _real_pin_position(comp, pin_num)
    except Exception:
        return
    if not pin_pos_mm:
        return
    pin_grid = (round(pin_pos_mm.x / 1.27), round(pin_pos_mm.y / 1.27))

    if net_name.startswith("NC_") or net_name.startswith("N$"):
        with contextlib.suppress(Exception):
            sch.no_connects.add(position=(pin_grid[0] * 1.27, pin_grid[1] * 1.27))
        return

    dx, dy = _outward_direction(comp, pin_num)
    # Asymmetric stubs: right/down labels start text AT anchor (extends outward),
    # left/up labels END text at anchor (text extends back toward symbol). Right-side
    # needs a longer stub so visible text isn't crammed against the symbol body.
    stub_len = 8 if (dx > 0 or dy > 0) else 4

    if net_name in POWER_SYMBOL_BY_NET:
        # Snap the power-symbol y to a per-net mod-4 residue so distinct power
        # nets never share a y-coordinate anywhere on the sheet (KiCad ERC's
        # y-coincidence bug uses that to false-merge nets).
        rail_offset = {"GND": 0, "5V_RAIL": 0, "3V3": 2}.get(net_name, 0)
        sym = POWER_SYMBOL_BY_NET[net_name]
        if net_name == "GND":
            base_y = pin_grid[1] + stub_len + rail_offset
        else:
            base_y = pin_grid[1] - stub_len - rail_offset
        end = (pin_grid[0], _power_symbol_y(net_name, base_y))
        with contextlib.suppress(Exception):
            sch.add_wire(start=pin_grid, end=end)
            sch.components.add(sym, pwr.pwr_ref(), sym.split(":")[-1], position=end)
        return

    # Outward-direction stub + label, with rotation matching pin direction.
    # Smaller font (0.8mm) so labels fit within tight pin spacing on big connectors.
    label_pos = (pin_grid[0] + dx * stub_len, pin_grid[1] + dy * stub_len)
    if dx > 0:
        label_rot = 0
    elif dx < 0:
        label_rot = 180
    elif dy > 0:
        label_rot = 270
    else:
        label_rot = 90
    with contextlib.suppress(Exception):
        sch.add_wire(start=pin_grid, end=label_pos)
        sch.add_label(net_name, position=label_pos, rotation=label_rot, size=0.8)


def _add_nc_at_pin(sch, comp, pin_num: str) -> None:
    """Place a no-connect marker at a component pin (mm coords)."""
    try:
        pos_mm = _real_pin_position(comp, pin_num)
    except Exception:
        return
    if not pos_mm:
        return
    with contextlib.suppress(Exception):
        sch.no_connects.add(position=(pos_mm.x, pos_mm.y))


def _place_pwr_flags(sch, pwr: PwrCounter, nets_used: set[str]) -> None:
    """Place ONE PWR_FLAG per used power net with unique x AND y per flag.

    Per kicad's y/x coincidence ERC false-merge bug, every PWR_FLAG must have
    a unique x AND a unique y from every other PWR_FLAG. Use index-based
    diagonal staggering to guarantee both.
    """
    for i, net_name in enumerate(sorted(nets_used)):
        sym = POWER_SYMBOL_BY_NET.get(net_name)
        if not sym:
            continue
        # Each PWR + FLG pair lands on the per-net mod-4 residue (same as inline
        # power-symbol routing) so the FLAG bank can't y-coincide with any other
        # power symbol on the sheet. Wire must be axis-aligned (KiCad treats
        # diagonals as graphics, not connections).
        # x-base 850 puts the bank in the empty right-of-SoM strip on A0
        # (936 grid wide); was 40 on A1 — that crammed the bank against the
        # power block and triggered false-merges.
        x = 850 + i * 30
        y_base = 28 + i * 4
        y = _power_symbol_y(net_name, y_base)
        flg_y = _power_symbol_y(net_name, y - 8)  # FLG below PWR, same residue
        with contextlib.suppress(Exception):
            sch.components.add(sym, pwr.pwr_ref(), sym.split(":")[-1], position=(x, y))
            sch.components.add(
                "power:PWR_FLAG", pwr.flg_ref(), "PWR_FLAG", position=(x, flg_y)
            )
            sch.add_wire(start=(x, y), end=(x, flg_y))


def _route_explicit_nets(
    sch, placed: dict, nets: list[dict], pwr: PwrCounter
) -> tuple[set[tuple[str, str]], set[str]]:
    """Stub each pin per its net (power symbol / NC marker / label). Returns (routed, pwr_nets_used)."""
    routed: set[tuple[str, str]] = set()
    pwr_nets_used: set[str] = set()
    for net in nets:
        if net["name"] in POWER_SYMBOL_BY_NET:
            pwr_nets_used.add(net["name"])
        if len(net["nodes"]) == 1:
            node = net["nodes"][0]
            comp = placed.get(node["ref"])
            if comp:
                _add_nc_at_pin(sch, comp, node["pin"])
                routed.add((node["ref"], node["pin"]))
            continue
        for node in net["nodes"]:
            comp = placed.get(node["ref"])
            if comp:
                _route_pin(sch, comp, node["pin"], net["name"], pwr)
                routed.add((node["ref"], node["pin"]))
    return routed, pwr_nets_used


def _add_orphan_no_connects(sch, placed: dict, routed: set[tuple[str, str]]) -> None:
    """Mark every un-routed pin as no-connect.

    Now that pin positions are computed correctly (via _real_pin_position with
    the y-inversion fix), large parts like BG95-M1 (102 pins, single-unit) work
    fine here too. The earlier >30 pin skip was a workaround for the y-inversion
    bug that's now fixed.
    """
    for ref, comp in placed.items():
        try:
            pins = comp.list_pins()
        except Exception:
            continue
        for pin in pins:
            num = pin["number"]
            if (ref, num) not in routed:
                _add_nc_at_pin(sch, comp, num)


def _power_driven_nets(nets: list[dict]) -> set[str]:
    """Power nets that already have a Power-output driver (regulator output).

    A PWR_FLAG on such a net would conflict with the driver — ERC sees two
    Power-output pins on one net and reports pin_to_pin. Skip them.
    """
    driven: set[str] = set()
    for net in nets:
        for node in net["nodes"]:
            ptype = node.get("pintype", "").upper().replace("_", "-")
            if "POWER-OUT" in ptype:
                driven.add(net["name"])
                break
    return driven


def _label_pins(sch, placed: dict, nets: list[dict]) -> None:
    pwr = PwrCounter()
    routed, pwr_nets_used = _route_explicit_nets(sch, placed, nets, pwr)
    _add_orphan_no_connects(sch, placed, routed)
    flag_nets = pwr_nets_used - _power_driven_nets(nets)
    _place_pwr_flags(sch, pwr, flag_nets)
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

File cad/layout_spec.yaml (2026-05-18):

sheet_size: A0
title: DLR Carrier Board
schematic_path: cad/dlr_carrier.kicad_sch
netlist_path: cad/dlr_carrier.net
blocks:
  power:
    origin:
    - 40
    - 40
    width: 400
    height: 260
  som:
    origin:
    - 480
    - 40
    width: 320
    height: 260
  sensors:
    origin:
    - 40
    - 340
    width: 400
    height: 200
  connectors:
    origin:
    - 40
    - 580
    width: 400
    height: 70
  cellular:
    origin:
    - 480
    - 340
    width: 300
    height: 200
  anemometer:
    origin:
    - 470
    - 590
    width: 300
    height: 70
  misc:
    origin:
    - 40
    - 655
    width: 800
    height: 5
layout_rules:
  routing: labels
  min_component_spacing: 8

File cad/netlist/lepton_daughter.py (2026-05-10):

"""Lepton daughterboard — FFC link from main carrier + Lepton mating header.

Per ADR-013: small (~25 x 40 mm) 4-layer PCB that hosts the FLIR Lepton 3.5
module, mounted to a sheet-metal tilt bracket inside the carrier enclosure.
The lens points down through an IR window in the enclosure floor; tilt is
set once at integration and locked with Loctite 243.

Schematic-stage uses a 14-pin THT header as a placeholder for the Lepton
mating socket, mirroring the main carrier's prior J8 convention. PCB layout
swaps the placeholder for the Molex 105028-1001 32-pin SMD socket footprint
(the actual Lepton mating connector) — same pattern as build_assembly.py's
MODEL_OVERRIDES on the main carrier. Pin map preserves the GroupGets 14-pin
breakout signal order so wiring stays identical end-to-end through the FFC.

Outputs:
- cad/lepton_daughter/lepton_daughter.net  — SKiDL-generated netlist
- cad/lepton_daughter/lepton_daughter.kicad_sch — minimal schematic
"""

import os
from pathlib import Path

_SYM_DIR = "/usr/share/kicad/symbols"
for _v in (
    "KICAD_SYMBOL_DIR",
    "KICAD6_SYMBOL_DIR",
    "KICAD7_SYMBOL_DIR",
    "KICAD8_SYMBOL_DIR",
    "KICAD9_SYMBOL_DIR",
):
    os.environ[_v] = _SYM_DIR

import kicad_sch_api as ksa  # noqa: E402
import skidl  # noqa: E402

PROJECT_ROOT = Path(__file__).resolve().parents[2]
NETLIST_PATH = PROJECT_ROOT / "cad/lepton_daughter/lepton_daughter.net"
SCHEMATIC_PATH = PROJECT_ROOT / "cad/lepton_daughter/lepton_daughter.kicad_sch"
PROJECT_PATH = PROJECT_ROOT / "cad/lepton_daughter/lepton_daughter.kicad_pro"

FP_C_0402 = "Capacitor_SMD:C_0402_1005Metric"
FP_C_0805 = "Capacitor_SMD:C_0805_2012Metric"
FP_FFC_14 = "Connector_FFC-FPC:Hirose_FH12-14S-0.5SH_1x14-1MP_P0.50mm_Horizontal"
FP_HEADER_14 = "Connector_PinHeader_2.54mm:PinHeader_1x14_P2.54mm_Vertical"


def _cap(value: str, fp: str, n1: skidl.Net, n2: skidl.Net) -> None:
    c = skidl.Part("Device", "C", value=value, footprint=fp)
    n1 += c[1]
    n2 += c[2]


def build_netlist() -> None:
    """SKiDL netlist for the Lepton daughterboard."""
    skidl.reset()
    # Power rails (sourced from main PCB through the FFC)
    v3v3 = skidl.Net("3V3")
    gnd = skidl.Net("GND")

    # 14-pin pinout (preserves GroupGets breakout signal order)
    spi_ce0 = skidl.Net("SPI0_CE0")
    spi_mosi = skidl.Net("SPI0_MOSI")
    spi_miso = skidl.Net("SPI0_MISO")
    spi_sck = skidl.Net("SPI0_SCLK")
    vsync = skidl.Net("GPIO25_VSYNC")
    sda = skidl.Net("SDA1")
    scl = skidl.Net("SCL1")
    pwr_dn = skidl.Net("LEPTON_PWR_DN_L")
    reset_n = skidl.Net("LEPTON_RESET_L")
    gpio3 = skidl.Net("LEPTON_GPIO3")

    # 14-pin FFC connector — mate to main PCB J8 FFC
    j_ffc = skidl.Part("Connector_Generic", "Conn_01x14", footprint=FP_FFC_14)
    j_ffc.value = "FFC_TO_MAIN"
    gnd += j_ffc[1]
    spi_ce0 += j_ffc[2]
    spi_mosi += j_ffc[3]
    spi_miso += j_ffc[4]
    spi_sck += j_ffc[5]
    vsync += j_ffc[6]
    gpio3 += j_ffc[7]
    sda += j_ffc[8]
    scl += j_ffc[9]
    pwr_dn += j_ffc[10]
    reset_n += j_ffc[11]
    gnd += j_ffc[12]
    v3v3 += j_ffc[13]
    v3v3 += j_ffc[14]

    # Lepton mating header — placeholder for the Molex 32-pin socket. PCB
    # layout swaps this to Connector_PinSocket_1.00mm at the time of layout.
    j_lep = skidl.Part("Connector_Generic", "Conn_01x14", footprint=FP_HEADER_14)
    j_lep.value = "LEPTON_SOCKET"
    gnd += j_lep[1]
    spi_ce0 += j_lep[2]
    spi_mosi += j_lep[3]
    spi_miso += j_lep[4]
    spi_sck += j_lep[5]
    vsync += j_lep[6]
    gpio3 += j_lep[7]
    sda += j_lep[8]
    scl += j_lep[9]
    pwr_dn += j_lep[10]
    reset_n += j_lep[11]
    gnd += j_lep[12]
    v3v3 += j_lep[13]
    v3v3 += j_lep[14]

    # Decoupling local to the Lepton VIN — 100 nF + 10 µF on 3V3
    _cap("100nF", FP_C_0402, v3v3, gnd)
    _cap("10uF", FP_C_0805, v3v3, gnd)

    # Pull-ups for active-low Lepton control lines (PWR_DN_L, RESET_L)
    r_pdn = skidl.Part(
        "Device", "R", value="10k", footprint="Resistor_SMD:R_0402_1005Metric"
    )
    pwr_dn += r_pdn[1]
    v3v3 += r_pdn[2]
    r_rst = skidl.Part(
        "Device", "R", value="10k", footprint="Resistor_SMD:R_0402_1005Metric"
    )
    reset_n += r_rst[1]
    v3v3 += r_rst[2]

    skidl.generate_netlist(file_=str(NETLIST_PATH), tool=skidl.KICAD8)


def _real_pin_grid(comp, pin_num: str):
    """Pin position in grid units, applying KiCad's symbol-to-sheet y-inversion."""
    pos = comp.get_pin_position(pin_num)
    if not pos:
        return None
    sym_y = comp.position.y
    real_y = 2 * sym_y - pos.y
    return (round(pos.x / 1.27), round(real_y / 1.27))


def build_schematic() -> None:  # noqa: C901
    """Minimal hand-laid schematic for the daughterboard."""
    pwr_counter = [0]

    def pwr_ref() -> str:
        pwr_counter[0] += 1
        return f"#PWR{pwr_counter[0]:03d}"

    ksa.use_grid_units(True)
    sch = ksa.create_schematic("Lepton Daughterboard")
    sch.set_paper_size("A4")
    sch.set_title_block(
        title="Lepton Daughterboard", company="Engineering With AI", rev="1.0"
    )

    # Two connectors side by side; passives below
    j_ffc = sch.components.add(
        "Connector_Generic:Conn_01x14", "J1", "FFC_TO_MAIN", position=(50, 60)
    )
    j_ffc.footprint = FP_FFC_14

    j_lep = sch.components.add(
        "Connector_Generic:Conn_01x14", "J2", "LEPTON_SOCKET", position=(140, 60)
    )
    j_lep.footprint = FP_HEADER_14

    pin_signals = [
        ("1", "GND"),
        ("2", "SPI0_CE0"),
        ("3", "SPI0_MOSI"),
        ("4", "SPI0_MISO"),
        ("5", "SPI0_SCLK"),
        ("6", "GPIO25_VSYNC"),
        ("7", "LEPTON_GPIO3"),
        ("8", "SDA1"),
        ("9", "SCL1"),
        ("10", "LEPTON_PWR_DN_L"),
        ("11", "LEPTON_RESET_L"),
        ("12", "GND"),
        ("13", "+3V3"),
        ("14", "+3V3"),
    ]

    # Stub each connector pin outward and label / power-symbol it
    for j_comp, sign in [(j_ffc, -1), (j_lep, +1)]:
        for pin_num, label in pin_signals:
            grid = _real_pin_grid(j_comp, pin_num)
            if not grid:
                continue
            stub_end = (grid[0] + sign * 4, grid[1])
            sch.add_wire(start=grid, end=stub_end)
            if label == "GND":
                sch.components.add("power:GND", pwr_ref(), "GND", position=stub_end)
            elif label == "+3V3":
                sch.components.add("power:+3V3", pwr_ref(), "+3V3", position=stub_end)
            else:
                rot = 180 if sign < 0 else 0
                sch.add_label(label, position=stub_end, rotation=rot, size=0.8)
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

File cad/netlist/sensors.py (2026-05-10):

"""IEEE 738 sensor suite: FLIR Lepton 3.5, DHT22, SI1145, ADS1115 + YL-83.

FLIR Lepton represented as a 14-pin breakout header (GroupGets module pinout).
DHT22 uses the DHT11 symbol (same physical layout) + 10k pull-up on data line.
SI1145 + YL-83 use generic module headers (Adafruit-style breakouts).
ADS1115IDGS reads YL-83 analog out on AIN0; I2C ADDR tied LOW for 0x48.
"""

import skidl

FP_C_0402 = "Capacitor_SMD:C_0402_1005Metric"
FP_R_0402 = "Resistor_SMD:R_0402_1005Metric"
FP_HEADER_2_54 = "Connector_PinHeader_2.54mm:PinHeader_1x{n}_P2.54mm_Vertical"


def _cap(value: str, fp: str, n1: skidl.Net, n2: skidl.Net) -> None:
    c = skidl.Part("Device", "C", value=value, footprint=fp)
    n1 += c[1]
    n2 += c[2]


def _res(value: str, fp: str, n1: skidl.Net, n2: skidl.Net) -> None:
    r = skidl.Part("Device", "R", value=value, footprint=fp)
    n1 += r[1]
    n2 += r[2]


def _module_header(n_pins: int, label: str) -> skidl.Part:
    """Single-row 2.54mm pin header for off-board sensor breakout modules."""
    p = skidl.Part(
        "Connector_Generic",
        f"Conn_01x{n_pins:02d}",
        footprint=FP_HEADER_2_54.format(n=f"{n_pins:02d}"),
    )
    p.value = label
    return p


def build_flir_lepton(
    v3v3: skidl.Net,
    gnd: skidl.Net,
    sda: skidl.Net,
    scl: skidl.Net,
    spi_mosi: skidl.Net,
    spi_miso: skidl.Net,
    spi_sck: skidl.Net,
    spi_ce0: skidl.Net,
    vsync: skidl.Net,
) -> None:
    """FLIR Lepton 3.5 SPI/I2C link via 14-pin FFC to off-board daughterboard.

    Per ADR-013: Lepton mounts on a separate daughterboard so its lens can be
    aimed at the conductor below the cross-arm independently of the main PCB.
    This function adds the Hirose FH12-14S-0.5SH FFC connector on the main
    carrier; the daughterboard (separate KiCad project under cad/lepton_daughter/)
    hosts the Molex 32-pin Lepton socket.

    Pin map preserves the GroupGets 14-pin breakout signal order so the same
    Lepton breakout schematic is reusable on the daughterboard.

    1=GND  2=CS   3=MOSI  4=MISO  5=SCK   6=VSYNC  7=GPIO3
    8=SDA  9=SCL  10=PWR_DN_L  11=RESET_L  12=GND  13=3V3  14=VIN
    """
    j = skidl.Part(
        "Connector_Generic",
        "Conn_01x14",
        footprint=(
            "Connector_FFC-FPC:" "Hirose_FH12-14S-0.5SH_1x14-1MP_P0.50mm_Horizontal"
        ),
    )
    j.value = "FLIR_LEPTON_FFC"
    gnd += j[1]
    spi_ce0 += j[2]
    spi_mosi += j[3]
    spi_miso += j[4]
    spi_sck += j[5]
    vsync += j[6]
    skidl.Net("LEPTON_GPIO3") & j[7]
    sda += j[8]
    scl += j[9]
    # PWR_DN_L and RESET_L pulled high through FFC (active-low, default-deasserted)
    _res("10k", FP_R_0402, j[10], v3v3)
    _res("10k", FP_R_0402, j[11], v3v3)
    gnd += j[12]
    v3v3 += j[13]
    v3v3 += j[14]  # VIN tied to 3V3 (daughterboard powered from main 3V3 rail)
    _cap("100nF", FP_C_0402, v3v3, gnd)


def build_dht22(v3v3: skidl.Net, gnd: skidl.Net, gpio4: skidl.Net) -> None:
    """DHT22 ambient temp/humidity — 4-pin module + 10k pull-up on data line."""
    u = skidl.Part("Sensor", "DHT11", footprint="Sensor:Aosong_DHT11_5.5x12.0_P2.54mm")
    u.value = "DHT22"
    v3v3 += u["VDD"]
    gnd += u["GND"]
    gpio4 += u["DATA"]
    _res("10k", FP_R_0402, gpio4, v3v3)
    _cap("100nF", FP_C_0402, v3v3, gnd)


def build_si1145(
    v3v3: skidl.Net, gnd: skidl.Net, sda: skidl.Net, scl: skidl.Net
) -> None:
    """SI1145 UV/visible/IR sensor — Adafruit-style 5-pin breakout.

    1=VIN  2=GND  3=SCL  4=SDA  5=INT (NC)
    """
    j = _module_header(5, "SI1145")
    v3v3 += j[1]
    gnd += j[2]
    scl += j[3]
    sda += j[4]
    skidl.Net("SI1145_INT") & j[5]
    _cap("100nF", FP_C_0402, v3v3, gnd)
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

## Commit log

2026-04-11 feat: scaffold from template
    [bom.csv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]
2026-04-12 📛 feat: add pipeline and coverage badges
2026-05-01 📝 docs: fix diagram arrow direction + label word-wrap
2026-05-09 🔌 feat: pivot to single-PCB DLR carrier (CM4 + cellular)
    Pivot from CM4 HAT to single-PCB carrier — full theory derivation, SKiDL
    netlist with 6 modules (power/som/cellular/sensors/connectors/model), block-aware
    schematic generator (kicad-sch-api), 12 system ADRs, manual PCB layout
    (DRC clean), and full fab outputs (gerbers/drill/STEP/BOM/CPL).
    Component gates locked: BQ24650 MPPT, LMR33630 buck, AP2112K + LP5907 LDOs,
    TXS0108E level shifter, Hirose U.FL antenna, Phoenix MKDS terminal blocks
    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
    [bom.csv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]
2026-05-10 📐 docs: spec for FLIR Lepton daughterboard mounting redesign
    Cross-arm-mounted DLR requires the Lepton lens to aim at a conductor below
    the cross-arm. The current main-PCB-mounted Lepton (lens perpendicular to
    +Z) can't be aimed without inverting the enclosure or folding the optical
    path with a mirror — both undesirable for 30-yr unattended deployment.
    This spec captures the converged design: split the Lepton onto a small
    daughterboard linked to the main PCB by a 14-pin FFC, mounted on a
    sheet-metal bracket with M3 pivot + arc-slot lock for ±15° aim adjustment
    at integration time. Adds a sealed industrial USB-C commissioning port so
    the integrator can preview the live thermal frame w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
2026-05-10 🔌 feat: J8 FFC + commissioning USB-C + schematic generator fixes
    Per ADR-013 (proposed in 2026-05-10-flir-mounting-design.md):
    SKiDL netlist:
    - J8 footprint changes from 14-pin THT 2.54mm header → Hirose FH12-14S-0.5SH
    FFC connector (sensors.py). Pin map preserves the GroupGets 14-pin Lepton
    breakout signal order so the daughterboard can reuse it.
    - New build_commissioning_usbc() adds a sealed industrial USB-C receptacle
    on the carrier for live thermal preview during integrator aim of the
    Lepton daughterboard tilt. UFP/device mode (5.1k Rd on CC1/CC2), VBUS NC.
    - Second USB pair on CM4 J5 (pins 36/37) routes the commissioning USB
    signals; the truly-unused pin list shrinks acc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
    [dlr_carrier.kicad_sch]
2026-05-10 🐛 fix: per-component hash jitter to avoid ERC false-merge cascade
    The y-mod-4 fix on power symbols handled cross-net y-coincidence between
    power symbols, but the underlying grid-based component placement still gave
    many components coincident pin y/x values, which KiCad's ERC then cascade-
    merged into spurious cross-net "two power outputs" and "multiple net names"
    errors.
    Adding a per-component (dx, dy) jitter using prime moduli (17, 23) on the
    component ref hash spreads pin positions enough to break the cascade. ERC
    goes from 1 error + 2 warnings to 0 errors + 3 warnings. The remaining
    warnings are pin_to_pin (Bidirectional ↔ Power output) and
    multiple_net_names false-positives that do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
    [dlr_carrier.kicad_sch]
2026-05-10 📝 docs: ADR-013 Lepton daughterboard + readme structure update
    ADR-013 documents the scoped exception to ADR-001's single-PCB rule for
    the Lepton mounting redesign. Includes context, decision, rationale,
    alternatives considered, and consequences. Index updated.
    Readme project-structure tree adds:
    - cad/netlist/lepton_daughter.py — daughterboard SKiDL
    - cad/lepton_daughter/ — second PCB KiCad project
    - cad/schematic/ + cad/assembly/ — generated artifacts
    Fabrication pipeline section calls out two PCBs.
2026-05-10 🔌 feat: Lepton daughterboard project (cad/lepton_daughter/)
    Per ADR-013. Small ~25 × 40 mm 4-layer board that mounts to a sheet-metal
    tilt bracket inside the carrier enclosure. Hosts the FLIR Lepton 3.5 module
    with its lens pointing down through an IR window in the enclosure floor.
    Components (schematic-stage placeholders; PCB layout swaps the Lepton mating
    header for the Molex 105028-1001 32-pin SMD socket, same pattern as the main
    carrier's MODEL_OVERRIDES in build_assembly.py):
    - J1: Hirose FH12-14S-0.5SH FFC connector (14 pins, mate to main carrier J8)
    - J2: 14-pin THT header placeholder for the Lepton Molex socket
    - C1: 100 nF / 0402 decoupling on 3V3
    - C2: 10 µF / 0805 bulk deco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
    [lepton_daughter.kicad_sch]
2026-05-10 🎨 feat: build_assembly.py renders Lepton daughterboard + bracket
    Per ADR-013. The vision_thermal group on the main PCB no longer stacks the
    Lepton can/lens on J8 — J8 is now the FFC connector to the daughterboard.
    Adds a new top-level cq.Assembly subassembly "lepton_daughterboard" with
    named nodes for the bake pipeline's material binding:
    - lepton_daughterboard__bracket brushed-aluminium sheet metal plate
    - lepton_daughterboard__pcb dark-blue 25 x 40 x 1.6 mm 4-layer
    - lepton_daughterboard__socket existing Molex 32-pin pedestal STEP
    - lepton_daughterboard__lepton_body matte gunmetal can
    - lepton_daughterboard__lepton_lens chrome bezel with recessed aperture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
    [lepton_daughter.py]
2026-05-10 🎨 fix: position lepton daughterboard so baked Lepton sits near J8
    Adjusts DAUGHTER_POS_MM so the lepton_body/lens — which the marketing bake
    keeps visible while hiding the bracket+pcb+socket scaffolding (ADR-013 is
    internal engineering detail) — lands at roughly the height the old Lepton-
    on-J8 placement had. Z = -5.1 mm offsets the daughterboard local frame so
    the visible Lepton bottom is at PEDESTAL_H above the PCB top.
    X,Y offset moves it to roughly the J8 (FFC connector) corner of the board.
2026-05-16 ♻️ refactor: rename ems-line-controller-dlr-pcb → dlr-pcb
    Drops BESS-side ems-line-controller framing; dlr- prefix groups under
    DLR brand. Hardware role unchanged.
2026-05-16 🔧 chore(cad): regenerate PCB layout, gerbers, and fab artifacts
    [bom.csv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]
2026-05-16 📝 docs: dlr-utility-envelope → dlr-operating-envelope in feed refs
2026-05-18 ✨ feat(anemometer): RS-485 wind sensor block + multi-sheet schematic
    Adds IEEE 738 wind input via SP3485EN RS-485 transceiver. Sensor is a
    field-replaceable SKU on the harness (Calypso ULP STD demo build, upgrade
    to Vaisala WMT702 / Gill WO65 for low-wind sites). One PCB, two SKUs.
    * theory.ipynb §6: derive dI/dV_w and dI/dphi from IEEE 738 sensitivity;
    required spec ±0.16 m/s, ±6°, ≤0.5 m/s threshold. Weibull climatology
    picks SKU per site.
    * cad/netlist/anemometer.py: SP3485EN + 120Ω term + 680Ω bias + SM712
    TVS + 250 mA polyfuse + M12 5-pin connector, VBAT-fed.
    * CM4: UART2 on GPIO0/1 (was USB2 placeholder), DE on GPIO6.
    * cad/schematic/multi_sheet.py: hierarchical schema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
    [dlr_carrier-anemometer.kicad_sch, dlr_carrier-cellular.kicad_sch, dlr_carrier-connectors.kicad_sch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]
2026-05-18 🎨 style: lint fixes (f-string, unused imports, complexity, naming)
    CI lint surface from the prior commit:
    * F541: drop extraneous `f` prefixes on f-strings without placeholders
    * F401: remove unused `math` and `_place_pwr_flags` imports
    * C901: extract `_route_sheet_nets` helper so `build_child_sheet`
    complexity drops back under the McCabe threshold
    * N806: lowercase local constants in `build_root_sheet`
    * black: reformat multi_sheet.py + schematic.py
    [dlr_carrier-anemometer.kicad_sch, dlr_carrier-cellular.kicad_sch, dlr_carrier-connectors.kicad_sch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]
2026-05-19 🪪 feat(anemometer): low-wind variant — Vaisala WMT702, kit SKU split
    Locks the low-wind variant per the grill-me design tree. Single PCB +
    single firmware binary; the variant lives in the kit BOM (sensor + cable
    harness + PV panel + battery). Both sensors speak NMEA 0183 over the
    RS-485 transceiver so the driver is talker-agnostic.
    Hardware:
    * anemometer.py: add SMBJ24CA TVS on V+→GND for IEC 61000-4-5 2 kV
    surge tolerance (utility-tower deployment).
    Theory:
    * theory.ipynb §6: variant-aware power-budget cell. WMT702's 480 mW
    draw needs a 30 W panel + 100 Wh battery to hold 1.66× winter margin
    and 2.22 d autonomy. High-wind kit (Calypso, 1 mW) stays on the
    existing 20 W / 5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
    [dlr_carrier-anemometer.kicad_sch, dlr_carrier-cellular.kicad_sch, dlr_carrier-connectors.kicad_sch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]
2026-05-19 🎨 feat(viewer): kit variant GLBs — Calypso vs Vaisala WMT702
    Extends cad/assembly/build_assembly.py with --variant {hw,lw,all} to emit
    a field-kit subassembly (sensor body + 5 m cable + PV panel + battery box)
    alongside the existing PCB GLB.
    Sensor geometry: primitives from datasheet dimensions (neither vendor
    publishes a public STEP). Calypso = Ø68x65 mm two-cylinder mushroom;
    WMT702 = Ø50x348 mm central mast + 3 transducer arms at 120° at the top.
    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
2026-05-23 📝 docs(owners): add ems-iso to platform-engineer
2026-05-23 📝 docs(owners): rename ems-iso → platform-ems-iso (platform-generated, not internal to EMS)
